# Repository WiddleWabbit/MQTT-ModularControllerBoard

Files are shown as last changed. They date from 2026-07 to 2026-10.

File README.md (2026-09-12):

# MQTT Modular Controller Board

*Currently In Testing - Not Yet Tested*

ESP32-S3-WROOM-1U based motherboard designed to communicate externally via MQTT, and read sensors, control interfaces and other hardware through purpose built modules. For example, actuator control (pumps, solenoids, etc.), and water sensor readings etc.

## Features

- ESP32-S3-WROOM-1U microcontroller with antenna support
- Four module slots using standardized 2x10 pin headers
- Power rails: 12 V, 5 V, and 3.3 V supplied to modules
- High-side reverse polarity protection on 12 V and 5 V inputs
- USB-powered operation for programming and testing (no 12 V required)
- Screw terminal power input
- 4-layer PCB designed for assembly (routing / GND / GND / routing)
- 4 x 3.5mm Mounting Holes

## Architecture

### Core Components
- **Microcontroller**: ESP32-S3-WROOM-1U
- **Power Input**: 12 V via screw terminals
- **Power Conversion**:
  - 12 V → 5 V using TPS563200DDCR (TI WEBENCH design)
  - 5 V → 3.3 V using LDO
- **Maximum Outputs**:
  - 12 V: Limited by external supply
  - 5 V: 3 A total (0.8 A used internally)
  - 3.3 V: 1 A total (0.6 A used by ESP32)

### Module Interface
Each of the four modules connects via two 10-pin headers and receives:
- Power: 12 V (4 pins shared), 5 V (2 pins), 3.3 V (2 pins), GND (4 pins)
- Communication:
  - Shared SPI: CS(per module), MOSI(GPIO11), MISO(GPIO13), SCK(GPIO12)
  - Shared I²C: SDA(GPIO4), SCL(GPIO5)
- Control/Detection:
  - One general-purpose GPIO per module
  - One module detection/sense pin per module
  - Module-specific CS pins.

#### Module Slots (Left to Right)
Slot 1:
- General Purpose: GPIO1
- Module Detection: GPIO2
- CS Pin: GPIO16
  
Slot 2:
- General Purpose: GPIO43
- Module Detection: GPIO44
- CS Pin: GPIO15
  
Slot 3:
- General Purpose: GPIO42
- Module Detection: GPIO41
- CS Pin: GPIO7
  
Slot 4:
- General Purpose: GPIO40
- Module Detection: GPIO39
- CS Pin: GPIO6
  
### Additional Features
- USB micro-B for programming and power (VBUS sense on GPIO08)
- Power indicator LED on 3.3 V rail
- EN button and RESET functionality
- Manual download mode: Hold BOOT button while pressing RESET, then release BOOT

### PCB Stackup
4-layer board:  
Component/Routing → Ground plane → Ground plane → Routing

Impedance Control:
Designed for JLCPCB Impedance Control Stackup of JLC04161H-7628, Finished thickness of 1.59mm.

## Setup and Build

**Firmware**: The PlatformIO firmware includes non-blocking WiFi station
reconnection and a captive-portal setup flow. On first boot, the portal scans
nearby networks and offers a selectable SSID list plus manual SSID entry.

**Programming**:
- Connect via USB micro-B.
- Use ESP32 flashing tools (esptool, Arduino IDE, ESP-IDF, etc.).
- For manual bootloader mode: Hold BOOT button, press RESET, release BOOT.

**Module Development**:
Modules must conform to the 2x10 header pinout with 40mm pitch.
Board uses 2 x 10, 8.5mm Female Headers (A2541HWV-10P). Recommended 3A support.

## Repository Contents

- KiCad schematic and PCB files
- Project configuration
- Backups folder

## License

This documentation is part of MQTT-ModularControllerBoard Project and is licensed under the CERN Open Hardware Licence Version 2 - Permissive (CERN-OHL-P-2.0). 
You may redistribute and modify this documentation under the terms of the CERN-OHL-P-2.0. 
This documentation is distributed WITHOUT ANY EXPRESS OR IMPLIED WARRANTY, INCLUDING OF MERCHANTABILITY, SATISFACTORY QUALITY AND FITNESS FOR A PARTICULAR PURPOSE. See the CERN-OHL-P-2.0 for applicable conditions.

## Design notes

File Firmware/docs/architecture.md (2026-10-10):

# Firmware architecture

[Home](home.md)

## Summary

The controller is seven modules. Each one has a small interface and hides its state machines. `src/main.cpp` is the composition root: it constructs the ESP32 adapters, passes timing constants and `kMqttDeviceId`, and calls `begin` / `update`. It does not sequence the steps inside a module.

Logic depends on hardware ports in `lib/Interfaces/`. ESP32 adapters live in `lib/Drivers/`. Logic does not include Arduino headers.

## Where it sits

Global constructors run before `setup()`. The type modules register their MQTT handlers there, so they exist before `Network::begin()`. `startController()` then calls `moduleBus.begin()`, `network.begin()`, and `serialConsole.begin()`. A latched programming session skips that until the session ends.

`kMqttDeviceId` in `src/main.cpp` is the MQTT topic root used when `mqtt_prefix` is not stored. The layout does not invent that id. `{id}` below means that root. Setting it is described in [configuration.md](configuration.md). Every topic, and a payload to publish when testing, is in the [MQTT reference](reference/mqtt.md).

## What main creates

```text
main.cpp
  Network
    WifiManager
    NtpService
    MqttService
    MqttTopicLayout
    PreferenceNetworkConfigStore
    NetworkRuntime
  ModuleBus
    ModuleHost
      SlotController
    ModuleSlotPublisher
  SensorModule
    SensorPoller
    SensorMqttBridge
  SolenoidModule
    SolenoidPoller
    SolenoidMqttBridge
  PumpModule
    PumpPoller
    PumpMqttBridge
  SerialConsole
    SerialConfigController
    SerialStatusReporter
  Programming
    ProgrammingSession
    IspProgrammer
    UpdiProgrammer
```

The ESP32 adapters (clock, Wi-Fi, NTP, MQTT, preferences, I2C, GPIO, USB serial, SPI, the half-duplex UART, and the programming latch) are also constructed in `main.cpp` and passed in. Sibling modules reach inside `Network` or `ModuleBus` through a private accessor. `main.cpp` does not call those accessors. On the bus, each `SlotController` holds one slot. `ModuleHost` calls I2C. `ModuleSlotPublisher` publishes that slot's public snapshot. The handoff is on the [module bus](module-bus.md) page.

## One pass

`loop()` always calls `network.update()` first. Inbound MQTT commands are queued there. `update()` methods do not wait on the network. Wi-Fi and MQTT retries use wrap-safe elapsed time and exponential backoff. An I2C transaction is bounded by the host's 50 ms timeout.

```mermaid
flowchart TD
  loop["loop()"] --> net["network.update()<br/>Wi-Fi, then NTP, then MQTT"]
  net --> prog{"programming.active()?"}
  prog -->|yes| stk["programming.update()"]
  stk --> still{"still active?"}
  still -->|yes| ret["return"]
  still -->|no| boot["clear the latch<br/>startController() if setup skipped it"]
  prog -->|no| ser["serialConsole.update()"]
  boot --> ser
  ser --> asked{"program command?"}
  asked -->|yes| arm["store the latch, programming.begin(), return"]
  asked -->|no| bus["moduleBus.update()"]
  bus --> sensor["sensorModule.update()"]
  sensor --> solenoid["solenoidModule.update()"]
  solenoid --> pump["pumpModule.update()"]
  pump --> snap["serialConsole.updateStatus()"]
```

An immediate `status` prints inside `serialConsole.update()`, before the modules. The periodic snapshot is `updateStatus()`, after them, so it matches this pass. Heap and PSRAM lines stay in `main.cpp` and print when USB is plugged in.

While a session is active, Wi-Fi, NTP, and MQTT keep running. The console, the bus, and the type modules do not. Desired solenoid and pump commands wait. Their absence windows keep counting, so a session longer than the cutoff turns those outputs off on the next module update.

## Modules

| Module | Interface | What one `update()` does | Page |
| --- | --- | --- | --- |
| `Network` | `begin`, `update`, `publish`, `addMessageHandler`, `apply`, `config` | Wi-Fi, then NTP, then MQTT | [Network](networking.md) |
| `SerialConsole` | `begin`, `update`, `updateStatus` | `update` reads USB lines. `updateStatus` prints the snapshot after the modules | [Serial console](serial-console.md) |
| `ModuleBus` | `begin`, `update`, `quiesce`, `resume` | At most one I2C transaction, then slot status if the text changed | [Module bus](module-bus.md) |
| `SensorModule` | `update` | At most one sensor exchange, then publish what it stored | [Sensor](sensor-module.md) |
| `SolenoidModule` | `update` | At most one solenoid exchange, then publish what it stored | [Solenoid](solenoid-module.md) |
| `PumpModule` | `update` | At most one pump exchange, then publish what it stored | [Pump](pump-module.md) |
| `Programming` | `begin`, `update`, `active` | ISP or UPDI until idle timeout or a confirmed unplug | [Programming](programming.md) |

Poll intervals and command-absence cutoffs are named constants in `src/main.cpp` and are passed into the type modules. Sensor, solenoid, and pump polls are 60 seconds. A solenoid command absent for 15 minutes turns every output off. A pump on/off command absent for 3 minutes turns the pump off. A pump reset does not refresh that window.

`Network` accepts at most four inbound handlers. Sensor, solenoid, and pump register one each, in their constructors. `begin` loads the stored record over the defaults from `main.cpp`, then starts Wi-Fi, MQTT, and NTP. `apply` persists the selected fields and pushes Wi-Fi or MQTT only after that save. An empty broker host stays unconfigured and does not call `connect`.

## Seams

A seam is a contract with two adapters. Hardware ports (`IClock`, `IWifi`, `INtpAdapter`, `IMqttClient`, `IPreferenceStore`, `ISerialPort`, `IBytePort`, `IDigitalPin`, `ISpiMaster`, `IHalfDuplexUart`, `I2cMaster`) have an ESP32 driver and a desktop fake. `INetworkConfigStore` lives in `lib/Logic/Network/` because `PreferenceNetworkConfigStore` and `FakeNetworkConfigStore` are both real adapters. It is not a hardware port. Port behaviour is in [interfaces.md](interfaces.md).

Do not add an interface so one logic class can be replaced by a fake. `WifiManager`, `NtpService`, `MqttService`, `ModuleHost`, and the pollers stay as classes inside their module. Their existing tests stay, because those tests cover edges the module tests do not replace.

## Folders

- `lib/Interfaces/` contains the hardware ports and `ModuleProtocol.h`.
- `lib/Drivers/` contains the ESP32 adapters.
- `lib/Logic/` is one PlatformIO library. Sources live in `Network`, `Console`, `Bus`, `Sensor`, `Solenoid`, `Pump`, and `Programming`.
- `test/test_desktop/fakes/` contains the desktop adapters.
- `test/test_desktop/` contains Unity tests. `test_main.cpp` calls each file's runner. `test_deep_modules.cpp` drives the seven modules. The other files drive the classes inside them.
- `src/main.cpp` composes the product.

`platformio.ini` lists `lib_deps = Logic` on both environments. The library finder does not compile sources that live in subfolders unless the library is named. The `-I lib/Logic/...` flags only expose the headers. Leave `lib_deps` in place.

## Desktop testing

Tests run on the desktop with PlatformIO's `native` environment:

```text
C:\Users\Nathan\.platformio\penv\Scripts\platformio.exe test -e native
```

`test_deep_modules.cpp` drives each module through its public interface: connect and backoff, apply and persistence, empty-broker refusal, slot publish and enumeration, prefix changes, sensor and solenoid and pump commands, absence windows, programming quiesce, and the serial console. The older files keep the inner edges: retry sequences, frame codecs, enumeration faults, poller cycles, and the STK500 and jtag2updi command sets.

The fakes simulate link state, RSSI, time, broker outcomes, subscriptions, publications, inbound messages, persisted settings, USB presence, serial bytes, GPIO levels, SPI, a half-duplex UART, and I2C slaves. The RTC programming record is ESP32-only and is not in these tests. Production builds use `lib/Drivers/`. Test code and fakes are not included.

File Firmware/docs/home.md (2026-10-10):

# Firmware

The controller is seven modules. `src/main.cpp` constructs them and calls
`update()`. It does not run the steps inside a module.

Start here. Three ways to read.

## How the controller runs

Each of these is a short page: what the module creates, and what one `update()` does.

1. [Architecture](architecture.md) — the loop, and who owns whom.
2. [Module bus](module-bus.md) — `SlotController` holds each slot; the host does one I2C transaction; the publisher sends slot status.
3. [Sensor](sensor-module.md), [Solenoid](solenoid-module.md), and [Pump](pump-module.md) — one daughter type each.
4. [Network](networking.md) — Wi-Fi, then NTP, then MQTT.
5. [Serial console](serial-console.md) — USB lines, then the snapshot.
6. [Configuration](configuration.md) — `set` stages, `apply` stores, and the three names.
7. [Programming](programming.md) — ISP or UPDI on one slot.
8. [Hardware ports](interfaces.md) — the interfaces Logic calls.

## When you need a byte, a state, or a test

The [reference index](reference/index.md) is the technical wiki. Each module page there has the commands, the sequences, the errors, and the desktop test that covers them. The [MQTT reference](reference/mqtt.md) lists every subscription and publication, with the payload to publish when testing.

## Building a daughter module

A daughter module is the board in a slot. That is separate from the classes inside a controller module.

1. [What a daughter module must do](daughter/contract.md).
2. [Frames, with worked bytes](daughter/frames.md).
3. [Add a new type](daughter/new-type.md) — the board, and the controller module that talks to it.

`lib/Interfaces/ModuleProtocol.h` is the command list daughter projects copy. If a byte on these pages and the header disagree, the header is the one the controller compiles.

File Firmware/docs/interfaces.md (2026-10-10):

# Hardware interfaces

[Home](home.md)

Hardware ports live in `lib/Interfaces/`. Drivers implement them for
ESP32/Arduino. Desktop tests use controllable fakes. A port is a seam
because both adapters exist. Logic-to-logic interfaces are not added here.

## `IClock`

- `millis()` returns a monotonic millisecond counter.
- Values may wrap at the counter width; consumers must use unsigned elapsed-time
  arithmetic.
- The fake clock supports deterministic advancement and wraparound tests.

## `IWifi`

- `begin(ssid, password)` starts one nonblocking station attempt.
- `status()` reports `Disconnected`, `Connecting`, or `Connected`.
- `rssi()` reports station signal strength in dBm.
- `localIp()` reports the station IPv4 address, or `0.0.0.0` when none is
  assigned.
- `setHostname(hostname)` stores the DHCP hostname committed on the next
  station start.
- `resetStationMode()` stops station mode so the next start commits that name.
  The ESP32 driver uses this because Arduino-ESP32 2.0 applies the hostname
  only when station mode changes.
- `disconnect()` stops the current attempt or connection.
- The driver must not wait for association inside `begin()`.
- The fake records credentials, hostname commits, mode resets, and
  disconnects, can return a sequence of link states, and exposes a settable
  RSSI and address.

## `INtpAdapter`

- `configure(server1, server2, server3, utcOffset, daylightOffset)` starts or
  refreshes platform SNTP configuration.
- `isSynchronized()` reports whether a valid epoch is available.
- `currentTime()` returns the synchronized Unix epoch, or the platform value
  when synchronization is not yet available.
- Configuration is asynchronous; the adapter must not block waiting for NTP.
- The fake records all configuration values and exposes synchronization and
  epoch controls.

## `IMqttClient`

- `setCallback()` installs the inbound payload callback and opaque context.
- `connect()` performs one broker attempt and returns its result.
- `connected()` reports the current broker state.
- `disconnect()` closes the broker session.
- `subscribe()` returns whether a topic subscription was accepted.
- `publish()` returns whether a publication was accepted. It takes a retain flag and no QoS. Outbound messages are QoS 0.
- `loop()` services the underlying MQTT transport.
- The topics this firmware subscribes to and publishes are in the [MQTT reference](reference/mqtt.md).
- The fake records all calls, supports result sequences, and can inject
  inbound messages.

The production adapters are intentionally thin: `Esp32Wifi` uses `WiFi`,
`Esp32NtpAdapter` uses `configTime()` and the system epoch, `Esp32Clock` uses
Arduino `millis()`, and `PubSubClientAdapter` wraps an existing
`PubSubClient`.

## `INetworkConfigStore`

This contract is not a hardware port and does not live in `lib/Interfaces/`.
It is inside `Network`. The load and save rules are in the
[network reference](reference/networking.md).

## `IPreferenceStore`

- `open` / `close` bracket one read or write session.
- `contains` reports a key without reading it. Callers use it before
  `readString` so a missing key does not surface a storage error.
- `writeString` returns the number of characters stored. Empty text returns 0
  on both success and failure; `contains` distinguishes them.
- `writeUShort` returns 2 on success.

## `ISerialPort`

- `isPlugged()` is a nonblocking snapshot of the USB serial plug state.
- `available()` reports pending bytes, `read()` consumes one byte, and
  `writeLine()` emits one response line.
- The serial controller must not consume or emit bytes while the USB serial
  link is unplugged.
- Fakes must provide queued input and inspectable output.

## `IBytePort`

- Raw bytes for programming traffic. Line framing stays on `ISerialPort`.
- `isPlugged()`, `available()`, and `read()` match the serial port.
- `write(data, length)` sends a buffer. A null pointer or a zero length
  writes nothing.
- The ESP32 adapter is the same USB CDC object as `ISerialPort`.
- Fakes queue input and record every written byte.

## `ISpiMaster`

- `begin(clockHz)` starts mode 0, MSB first, with SCK idle low.
- `end()` releases the bus.
- `transfer()` clocks one byte and returns the byte shifted in.
- The programmer calls `begin()` before it drives reset low, and it keeps
  the clock at 125 kHz.
- Fakes record the clock, the order `begin()` was called, and every byte,
  and they return a scripted MISO stream.

## `IHalfDuplexUart`

- `attach(gpio, baud)` claims one GPIO as both TX and RX.
- `detach()` stops the UART and releases the pin.
- `available()` reports pending bytes. `read()` returns one byte, or -1
  when none arrives.
- `write()` sends raw bytes. The caller reads the local TX echo before
  the next byte. The ESP32 adapter is UART1, 8E2, and does not discard
  that echo. UART0 stays free because GPIO43 and GPIO44 are module pins.
- Fakes queue the echo ahead of any scripted target byte, and they record
  the GPIO, the baud, and every transmitted byte.

## `IDigitalPin`

- `setMode()` selects `DigitalInput`, `DigitalInputPullup`, `DigitalOutput`,
  or `DigitalOutputOpenDrain`. Names avoid Arduino `INPUT`/`OUTPUT` macros.
- `DigitalOutputOpenDrain` drives LOW as the safe default after mode change.
- `read()` is true when the pin is HIGH. Sense present is LOW.
- `write()` drives an output; true is HIGH / open-drain Hi-Z.
- The ESP32 driver must use Arduino `pinMode` so UART0 detaches from GPIO43/44.
- Fakes must record mode, writes, push-pull HIGH attempts, and an external
  level override for sense.

## `I2cMaster`

- `begin()`, `setClockHz()`, and `setTimeoutMs()` configure the bus.
- `write()` issues STOP. `writeRead()` uses a repeated start. A NACK,
  timeout, or bus error is returned to the caller. The ESP32 driver does
  not print a NACK. The console reports `Slot N: Nack` once.
- `recover()` clocks SCL up to nine times, issues STOP, and re-inits. It is
  best-effort; a still-stuck SDA needs the module unplugged.
- Results are `Ok`, `Nack`, `Timeout`, or `BusError`.
- Fakes record operations (address, tx, rxLen, STOP) and dispatch to
  simulated modules. They must support stuck-SDA and two-ACK collision.

Module command IDs, frame layout, and CRC-8/SMBus live in copyable
`lib/Interfaces/ModuleProtocol.h`. Behaviour a daughter board must follow
is in [the daughter contract](daughter/contract.md).

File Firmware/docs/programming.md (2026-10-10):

# Programming

[Home](home.md) · Reference: [Programming](reference/programming.md)

## Summary

`Programming` is an ISP or UPDI session on one firmware slot, 1 through 4. `program 1 isp` uses the shared SPI pins and that slot's CS pin as RESET. `program 3 updi` uses only that slot's CS pin as the UPDI wire. A line without both a slot and a method replies `ERR program` and does not start a session.

## Where it sits

`main.cpp` constructs it with the USB byte port, the SPI master, the half-duplex UART, the four CS pins, `kProgrammingPins`, `ModuleBus`, the clock, `kProgrammingIdleTimeoutMs` (60 seconds), and `kProgrammingUnplugTimeoutMs` (1 second). `loop()` calls `network.update()` first. While `active()` is true it calls `programming.update()` and returns, unless the session ended on that pass.

`serialConsole.update()` recognizes the program line and returns before the bus. `loop()` then stores the RTC latch and calls `begin(slot, method)`.

## What it creates

```text
main.cpp
  Programming
    ProgrammingSession     silence timer and the seen-then-absent unplug rule
    IspProgrammer          STK500v1 subset avrdude uses, 125 kHz SPI
    UpdiProgrammer         jtag2updi, one open-drain GPIO, 115200 8E2
```

`begin(slot, method)` quiesces the bus. A slot outside 1..4 returns without quiescing. A second `begin` while the session is active does not rebind the pin or the UART. While the session is active the console, the bus, and the type modules do not run. Wi-Fi, NTP, and MQTT do. Desired solenoid and pump commands wait, and their absence windows keep counting.

## One update

```mermaid
flowchart TD
  cmd["program N isp or program N updi"] --> ok["OK programming, pin line, RTC record"]
  ok --> begin["Programming.begin(slot, method) quiesces the bus"]
  begin --> step["programming.update(): one ISP or UPDI step"]
  step --> done{"60 s of silence, or 1 s absent after the link was seen?"}
  done -->|no| step
  done -->|yes| resume["Release the claimed CS pin, clear the record, resume the bus"]
```

A USB-open restart keeps the record, so `setup()` enters the same slot and method without the banner and without `startController()`. The reset button and a power cycle clear it. An older single-word ISP marker does not resume. Pins, the two host tools, and the wire sequences are in the reference.

## What is stored, and who reads it

The latch is one record in RTC slow memory (`.rtc_noinit`): magic, slot, and method. `setup()` reads it. `loop()` clears it when the session ends. Ending the session does not reset the chip. If init already ran, the power-on lines are not printed again.

## See also

- [Programming reference](reference/programming.md) — jumper pins, STK500, jtag2updi, the unplug rule, tests.
- [Configuration reference](reference/configuration.md) — the accepted `program` lines and `ERR program`.
- [MQTT reference](reference/mqtt.md) — commands that can still arrive while a session is active.
- [Serial console](serial-console.md)
- [Module bus](module-bus.md)
- [Architecture](architecture.md)

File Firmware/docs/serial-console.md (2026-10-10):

# Serial console

[Home](home.md) · Reference: [Serial console](reference/serial-console.md)

## Summary

`SerialConsole` reads USB command lines and prints the status snapshot. `update()` reads lines. `updateStatus()` prints the snapshot after the modules, so the slot lines match this pass. An immediate `status` command prints inside `update()`, before the modules.

USB plug state gates input and both kinds of print. Heap and PSRAM lines stay in `main.cpp`. They are not part of this snapshot.

## Where it sits

`main.cpp` constructs it with the serial port, the clock, `Network`, `ModuleBus`, `kSerialStatusIntervalMs` (10 seconds), and `kProgrammingPins`. `startController()` calls `serialConsole.begin()` after `network.begin()`. `loop()` calls `update()` before the bus, and `updateStatus()` after the pump module.

## What it creates

```text
main.cpp
  SerialConsole
    SerialConfigController     set, apply, status, program
    SerialStatusReporter       Wi-Fi, NTP, MQTT, and four slot lines
```

The reporter is constructed with the Wi-Fi, NTP, and MQTT services from `Network`, and with `ModuleHost` from `ModuleBus`. `main.cpp` does not construct it. It reads snapshots only. It does not call `ping()` or `echo()`.

## One pass

```mermaid
flowchart TD
  upd["SerialConsole.update()"] --> plug{"USB plugged in?"}
  plug -->|no| stop["Read nothing"]
  plug -->|yes| line["Read a complete line"]
  line --> cmd{"Command"}
  cmd -->|set| stage["Stage one field"]
  cmd -->|apply| save["NetworkRuntime saves the staged fields"]
  cmd -->|status| now["Print one snapshot now"]
  cmd -->|program| arm["Ask loop to start the programming session"]
```

`updateStatus()` prints the same snapshot when periodic reporting is on, the link is plugged in, and `kSerialStatusIntervalMs` has elapsed. `status` prints even when periodic reporting is off. It does not change the on/off flag. A successful immediate print restarts the wait until the next periodic snapshot.

A slot that reaches `Fault Nack` also prints one line, `Slot N: Nack`, on the next `updateStatus()`. That line is not repeated while the slot keeps failing and retrying. It is printed again after the slot is empty, online, or unsupported and then faults again. The I2C driver does not print its own NACK line.

`program` inside `update()` makes `loop()` store the RTC latch and call `programming.begin()` before the bus runs. The command list is in [Configuration](configuration.md). The session is in [Programming](programming.md).

## What is stored, and who reads it

Staged fields live in `NetworkRuntime` until `apply`. The on/off flag is the NVS key `status_report`. The snapshot interval is session RAM from `main.cpp`. No command stores it. Reboot restores 10 seconds.

The four slot lines come from `ModuleHost` public snapshots. Wi-Fi, NTP, and MQTT lines come from those services.

## See also

- [Serial console reference](reference/serial-console.md) — the seven lines, plug gating, tests.
- [Configuration](configuration.md)
- [Programming](programming.md)
- [Architecture](architecture.md)

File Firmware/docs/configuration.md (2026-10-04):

# Runtime configuration

[Home](home.md) · Reference: [Commands and stored fields](reference/configuration.md)

## Summary

`set` stages one field. `apply` stores only the fields staged since the last successful apply, then restarts Wi-Fi when a Wi-Fi field changed and MQTT when an MQTT field changed. A failed save leaves the active record unchanged and leaves the staged fields in place for a retry. An empty `apply` replies `OK applied` and does not reconnect.

## Where it sits

`SerialConfigController`, inside [Serial console](serial-console.md), parses complete lines while USB is plugged in. `NetworkRuntime`, inside [Network](networking.md), owns the active strings and the staged copy. `PreferenceNetworkConfigStore` writes them through `IPreferenceStore`.

## One apply

```mermaid
flowchart TD
  setc["set key value"] --> staged["Staging copy only"]
  staged --> apply["apply"]
  apply --> any{"Any field staged?"}
  any -->|no| ok["OK applied, no reconnect"]
  any -->|yes| save["Save those fields"]
  save --> fail{"Save succeeded?"}
  fail -->|no| keep["Active record unchanged, staged fields kept"]
  fail -->|yes| wifi{"A Wi-Fi field changed?"}
  wifi -->|yes| wre["Restart Wi-Fi"]
  save --> mqtt{"An MQTT field changed?"}
  mqtt -->|yes| mre["Restart MQTT"]
```

Setting a credential or a broker field to an empty string stores that empty string. An empty MQTT host stays `Unconfigured` and does not call `connect`.

## The three names

| Setting | Command | Missing key |
| --- | --- | --- |
| DHCP hostname | `set wifi.hostname` | `watering-controller` from `setup()`, not written until applied |
| MQTT client id | `set mqtt.client` | `watering-controller`, then saved on boot |
| Topic prefix `{id}` | `set mqtt.prefix` | `kMqttDeviceId` in `src/main.cpp` (`watering`), not written until applied |

The layout does not invent `watering`. The hostname, the client id, and the prefix are independent. A DHCP rename does not move topics. Two boards on one broker need different client ids and different prefixes. Commissioning sets all three to the same name. The character rules, the replies, and that example are in the [configuration reference](reference/configuration.md).

`{id}` in the other pages is this prefix.

## See also

- [Configuration reference](reference/configuration.md) — every key, NVS names, prefix generation.
- [MQTT reference](reference/mqtt.md) — every topic under that prefix, and a payload to publish when testing.
- [Serial console](serial-console.md)
- [Network](networking.md)

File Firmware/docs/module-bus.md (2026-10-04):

# Module bus

[Home](home.md)

Reference: [pins, phases, the lock, and publication](reference/module-bus.md).

## Summary

`ModuleBus` is the four-slot I2C bus. `main.cpp` creates it. A `SlotController` holds each slot's state. `ModuleHost` owns those four controllers, grants the enumeration lock, and is the class that talks to the I2C master. `ModuleSlotPublisher` reads the public snapshot and publishes a retained slot line when that line's text changed. Each `update()` lets the host do at most one I2C transaction, then asks the publisher. Sensor, solenoid, and pump borrow the same host later in the pass, each for one transaction of their own.

## Where it sits

`main.cpp` constructs `ModuleBus` with the I2C master, the clock, the four sense / MOD / CS pin sets, and `Network`. `loop()` calls `moduleBus.update()` after the console has read a command, and before the type modules. See [Architecture](architecture.md).

`Programming::begin()` calls `quiesce()` so the bus stays quiet during an ISP session, and `resume()` when the session ends. `loop()` skips `moduleBus.update()` for the whole session, so the publisher is quiet then too.

## What it creates

```text
main.cpp
  ModuleBus                 calls the host, then the publisher
    ModuleHost              owns the four controllers, the lock, and the I2C calls
      SlotController        one per slot; holds that slot's state and proposes the next step
    ModuleSlotPublisher     turns the public snapshot into retained {id}/slot/1 .. {id}/slot/4
```

`SlotController` watches SENSE, MOD, and CS for its slot. It remembers the phase, the address, the identity, and the last fault, and it proposes the next I2C operation. `ModuleHost` performs that operation and writes the result back onto the same controller. `ModuleSlotPublisher` reads the public snapshot through the host. I2C stays in the host. MQTT stays in the publisher.

## How they link

```text
each SlotController advances its pins
        |
ModuleHost grants the lock to the lowest slot that wants it
        |
the lock owner's enumeration step, else one due health ping, else no I2C
        |
applyI2cResult() on that slot when a transaction ran
        |
ModuleSlotPublisher reads every slot's public snapshot
        |
retained {id}/slot/N for each body the broker has not accepted yet
```

The lock owner's enumeration step is the transaction when one is due. A slot can hold the lock while it waits out the MOD settle or a retry gap. On those passes it proposes nothing, and a health ping for another slot can use the transaction. With neither due, the pass has no I2C. The publisher still runs, and it skips any slot whose text the broker already accepted.

## One update

```mermaid
flowchart TD
  upd["ModuleBus.update()"] --> pins["Each SlotController reads SENSE and advances its phase"]
  pins --> lock["ModuleHost grants the lock to the lowest waiting slot"]
  lock --> pick{"Lock owner has an enumeration step due?"}
  pick -->|yes| issue["Host issues that one transaction<br/>and the slot stores the result"]
  pick -->|no| health{"A health ping is due?"}
  health -->|yes| ping["Host issues that one ping<br/>and the slot stores the result"]
  health -->|no| pub["ModuleSlotPublisher"]
  issue --> pub
  ping --> pub
  pub --> changed{"Text differs from the last payload the broker accepted?"}
  changed -->|yes| mqtt["Publish retained {id}/slot/N"]
  changed -->|no| done["Leave that topic as it is"]
```

Sibling modules reach the host through `ModuleBus::host()`. `main.cpp` does not call that. A type module's `exchange()` is a later call in the same `loop()` pass. It uses the address and type the slot controller stored.

## What is stored, and who reads it

Each `SlotController` stores that slot:

- the private phase, which `state()` folds into `Empty`, `Debouncing`, `Enumerating`, `Online`, `Unsupported`, or `Fault`
- the assigned address, which stays 0 until a ping at that address succeeds. The ping follows `SET_ADDRESS`, or it follows three NACKs at `0x0A`. The slot address is `0x10` plus the slot index. Unplug and a controller reset both clear it.
- type id, protocol version, firmware version, and identity epoch
- the last fault (`None`, `Nack`, `BadCrc`, `BadFrame`, `Timeout`, or `Busy`)

`identityEpoch` increases by one each time `GET_IDENTITY` succeeds, including after the module restarts. Sensor, solenoid, and pump read it through the host. They clear that slot's cached readings when the slot leaves their type, and when this count changes.

`ModuleHost` stores which slot holds the enumeration lock (`-1` when the lock is free) and which slot to ask next for a health ping. Its readers (`state`, `address`, `typeId`, `protocolVersion`, `firmwareVersion`, `identityEpoch`, `fault`, `typeName`) forward to the matching controller. An out-of-range index reads as empty.

`ModuleSlotPublisher` stores, per slot, the last payload the broker accepted and whether that publish succeeded, plus the topic generation those payloads belong to. Every update builds the text again from the host. The words come from `writeSlotStatusBody` in `SlotStatusText`: `Empty`, `Debouncing`, `Enumerating`, `Online Sensor addr=0x10`, `Unsupported type=0x02AA addr=0x12`, `Fault Nack`. Firmware index 0 is topic `{id}/slot/1`.

- `SerialConsole` prints that same body with a `Slot N:` prefix.
- `SensorModule`, `SolenoidModule`, and `PumpModule` call `exchange()` for their own command after this `update()` has returned, and they keep their own samples.
- `Programming` calls `quiesce()` and `resume()`. While the host is quiesced, an `update()` leaves every slot where it is.

## See also

- [Module bus reference](reference/module-bus.md) — the phase map, the publisher's retry rule, pins, the lock, faults, and health pings.
- [MQTT reference](reference/mqtt.md) — the slot topics, and the payload text.
- [What a daughter module must do](daughter/contract.md)
- [Architecture](architecture.md)

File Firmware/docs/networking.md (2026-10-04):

# Network

[Home](home.md) · Reference: [Network](reference/networking.md)

## Summary

`Network` is Wi-Fi, NTP, MQTT, and the stored settings. `update()` runs those three in that order and does not decode sensor, solenoid, or pump commands. Inbound payloads are delivered to the handlers those modules registered.

An empty broker host stays unconfigured and does not call `connect`.

## Where it sits

`main.cpp` constructs it with the Wi-Fi, NTP, and MQTT adapters, the clock, the preference store, `kMqttDeviceId`, `kNtpConfig`, and `kNetworkTiming`. `startController()` calls `network.begin()` after `moduleBus.begin()`. `loop()` calls `network.update()` first on every pass, including while an ISP session is active.

The type modules exist before `begin()`, because their constructors register handlers.

## What it creates

```text
main.cpp
  Network
    WifiManager                      Idle, Connecting, Connected, Backoff
    NtpService                       Idle, WaitingForSync, Synchronized
    MqttService                      connect, subscribe, publish
    MqttTopicLayout                  topic strings and the generation counter
    PreferenceNetworkConfigStore     NVS through IPreferenceStore
    NetworkRuntime                   active record, staged edits, apply
```

`main.cpp` does not call those classes. Sibling modules reach MQTT and the topic tree through private accessors.

## One update

```mermaid
flowchart TD
  upd["Network.update()"] --> wifi["WifiManager.update()"]
  wifi --> ntp["NtpService.update()"]
  ntp --> mqtt["MqttService.update(wifi ready)"]
  mqtt --> fan["Deliver queued payloads to the registered handlers"]
```

None of these steps waits for a connection. Retries use wrap-safe elapsed time and capped exponential backoff.

`begin()` loads the stored record over the defaults from `main.cpp`, then starts Wi-Fi, MQTT, and NTP. `apply` stores the staged fields and pushes Wi-Fi or MQTT only after that save.

## What is stored, and who reads it

`NetworkRuntime` holds the active strings. Staged serial edits cannot change them before `apply`. `MqttTopicLayout` holds the topic tree for `{id}`. Its generation starts at 1 and increases when the id text changes, so publishers send their current values once under the new root.

`{id}` is `kMqttDeviceId` (`watering`) until `mqtt_prefix` is stored. The layout does not invent that id. Setting it is described in [Configuration](configuration.md).

The hostname, the MQTT client id, and the topic prefix are three different settings.

## See also

- [Network reference](reference/networking.md) — states, subscriptions, the generation counter, the config store.
- [MQTT reference](reference/mqtt.md) — every command, result, and a payload to publish when testing.
- [Configuration](configuration.md)
- [Architecture](architecture.md)

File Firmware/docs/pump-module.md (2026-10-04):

# Pump module

[Home](home.md) · Reference: [Pump](reference/pump-module.md)

## Summary

`PumpModule` talks to daughter boards of type `0x0300`. A board drives one pump. The module reads it when the board is identified, reads it again on the poll interval, and publishes `on`, `off`, or `fault`. `{id}/pump` names the desired on or off state, or asks for a reset. `SET_PUMP` is sent only when the known state differs, and it is not sent while the pump is faulted.

If no accepted on/off command arrives for `kPumpCommandTimeoutMs` (3 minutes), a pump that is on is turned off. A reset does not refresh that window, and it does not clear a fault by itself. `RESET_PUMP` is sent only after `{id}/pump` says `reset`.

## Where it sits

`main.cpp` constructs it with `ModuleBus`, `Network`, the clock, `kPumpPollIntervalMs` (60 seconds), and the absence window. The constructor registers the `{id}/pump` handler. `loop()` calls `pumpModule.update()` after the solenoid module.

## What it creates

```text
main.cpp
  PumpModule
    PumpPoller         one query per pass; per-slot state and timer
    PumpMqttBridge     records on, off, or reset; publishes the stored state
```

The callback only records the request. `ModuleHost` is the only I2C caller. This exchange is separate from the host transaction and from the sensor and solenoid queries.

## One update

```mermaid
flowchart TD
  upd["PumpModule.update()"] --> poll["PumpPoller: at most one exchange"]
  poll --> order["A missing state, else RESET, else SET, else the periodic read"]
  order --> mem["Store the state"]
  mem --> bridge["PumpMqttBridge"]
  bridge --> pub{"A state was stored this pass?"}
  pub -->|yes| mqtt["Publish retained on, off, or fault"]
  pub -->|no| quiet["Leave the broker as it is"]
```

A reset waits until the state is known. When it returns off or on and the desired state still differs, a later pass sends `SET_PUMP`. A reset that still returns fault is published and not followed by `SET_PUMP`.

## What is stored, and who reads it

Each slot keeps its own state, desired on/off, and poll timer. The absence window is one timer for every pump: any accepted on/off command restarts it. Faulted pumps are not reset when the window elapses. The bridge publishes `{id}/slot/N/pump`. Unplug publishes retained `unavailable` once.

Serial status prints the slot line only. The pump state is the MQTT payload.

## See also

- [Pump reference](reference/pump-module.md) — commands, reset, the cutoff, tests.
- [MQTT reference](reference/mqtt.md) — the pump topics, and a payload to publish when testing.
- [Daughter contract](daughter/contract.md)
- [Module bus](module-bus.md)
- [Architecture](architecture.md)

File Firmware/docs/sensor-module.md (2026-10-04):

# Sensor module

[Home](home.md) · Reference: [Sensor](reference/sensor-module.md)

## Summary

`SensorModule` talks to daughter boards of type `0x0200`. A board reports up to 16 inputs. The module learns that count when the board is identified, then reads presence and a raw value for each input. Every stored reading is published, including a repeated value.

Wire indexes are 0-based. MQTT slot and sensor numbers are 1-based. The controller does not scale the value.

## Where it sits

`main.cpp` constructs it with `ModuleBus`, `Network`, the clock, and `kSensorPollIntervalMs` (60 seconds). The constructor registers the handler for `{id}/sensor/read` and `{id}/sensor/connected`, before `Network::begin()`. `loop()` calls `sensorModule.update()` after `moduleBus.update()` and before the solenoid module.

## What it creates

```text
main.cpp
  SensorModule
    SensorPoller         one query per pass; per-slot count, samples, and timer
    SensorMqttBridge     publishes stored readings and the connected list
```

`ModuleHost`, inside the bus, is the only I2C caller. The poller's exchange is separate from the one transaction inside `moduleBus.update()`.

## One update

```mermaid
flowchart TD
  upd["SensorModule.update()"] --> poll["SensorPoller: at most one exchange"]
  poll --> order["Immediate read, else a missing count, else the next cycle step"]
  order --> mem["Store the count or the sample"]
  mem --> bridge["SensorMqttBridge"]
  bridge --> pub{"A reading was stored, or the connected list changed?"}
  pub -->|yes| mqtt["Publish the retained reading, and the list when it changed"]
  pub -->|no| quiet["Leave the broker as it is"]
```

The callback for `{id}/sensor/read` only enqueues a slot and a sensor index. The poller sends `GET_SENSOR_READING` on a later pass. While the count is still unknown, that request waits and the count query runs instead. `{id}/sensor/connected` only asks for the connected-input list. It does not enqueue a reading.

## What is stored, and who reads it

Each slot keeps its own count, samples, revision, and poll timer. The bridge reads those and publishes `{id}/slot/N/sensor/M` when a reading was stored, and `{id}/slot/N/sensors` as the count plus the connected indexes. Unplug publishes retained `unavailable` once for that slot's inputs and for its list. Another slot keeps its own cache.

Serial status prints the slot line (`Online Sensor addr=0x10`). It does not print individual inputs.

## See also

- [Sensor reference](reference/sensor-module.md) — commands, poll order, publish rules, tests.
- [MQTT reference](reference/mqtt.md) — the sensor topics, and a payload to publish when testing.
- [Daughter contract](daughter/contract.md)
- [Module bus](module-bus.md)
- [Architecture](architecture.md)

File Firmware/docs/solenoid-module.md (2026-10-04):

# Solenoid module

[Home](home.md) · Reference: [Solenoid](reference/solenoid-module.md)

## Summary

`SolenoidModule` talks to daughter boards of type `0x0100`. A board drives up to 16 outputs. The module learns that count when the board is identified, reads each output, and publishes `on`, `off`, or `disconnected`. An MQTT command names the desired on/off state of every output. The module sends `SET_SOLENOID` only where the known state differs.

If no accepted command arrives for `kSolenoidCommandTimeoutMs` (15 minutes), every output is turned off. Commands are expected about once a minute, and each one names the full set.

## Where it sits

`main.cpp` constructs it with `ModuleBus`, `Network`, the clock, `kSolenoidPollIntervalMs` (60 seconds), and the absence window. The constructor registers the handler for `{id}/solenoids` and `{id}/solenoids/connected`. `loop()` calls `solenoidModule.update()` after the sensor module.

## What it creates

```text
main.cpp
  SolenoidModule
    SolenoidPoller         one query per pass; per-slot count, states, and timer
    SolenoidMqttBridge     records desired state; publishes stored states
```

The callback only records the desired state. It does not touch I2C. `ModuleHost` is the only I2C caller. This exchange is separate from the host transaction and from the sensor query, so one `loop()` can carry one of each.

## One update

```mermaid
flowchart TD
  upd["SolenoidModule.update()"] --> poll["SolenoidPoller: at most one exchange"]
  poll --> order["A missing count, else a command step, else the next state read"]
  order --> mem["Store the count or the state"]
  mem --> bridge["SolenoidMqttBridge"]
  bridge --> pub{"A state was stored, or the inventory changed?"}
  pub -->|yes| mqtt["Publish the retained output, and the connected list when it changed"]
  pub -->|no| quiet["Leave the broker as it is"]
```

A command step reads an output whose state is still unknown, or sends `SET_SOLENOID` where the known state differs. A disconnected output is left alone. A command whose word count does not match the module count is not applied.

## What is stored, and who reads it

Each slot keeps its own count, output states, desired state, and poll timer. The absence window is one timer for the whole controller: any accepted `{id}/solenoids` command restarts it. The bridge publishes `{id}/slot/N/solenoid/M` from the stored state, and `{id}/slot/N/solenoids` as the count plus the connected indexes.

Serial status prints the slot line only.

## See also

- [Solenoid reference](reference/solenoid-module.md) — commands, the cutoff, the inventory, tests.
- [MQTT reference](reference/mqtt.md) — the solenoid topics, and a payload to publish when testing.
- [Daughter contract](daughter/contract.md)
- [Module bus](module-bus.md)
- [Architecture](architecture.md)

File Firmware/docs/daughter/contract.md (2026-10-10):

# What a daughter module must do

[Home](../home.md)

The controller is the only I2C master. Four slots share SDA and SCL. Your board sits in one slot and answers the frames below. Copy `lib/Interfaces/ModuleProtocol.h` for the command bytes and `crc8Smbus()`.

If this page and the header disagree on a byte value, the header is the one the controller compiles.

Worked bytes are in [Frames](frames.md). Choosing a type id, and the controller-side module that talks to a new board, are in [Add a new type](new-type.md). How the host walks the slots is in the [module bus reference](../reference/module-bus.md).

## You must

- Tie SENSE to GND while the board is seated. The controller's pull-up reads LOW as present.
- Leave the I2C slave off until MOD is released. The controller uses MOD as an input with a pull-up when it is not selecting you.
- ACK `0x0A` only while MOD is low, within 5 ms of that edge (`kModGateMaxMs`). Never ACK `0x0A` as a reset default.
- NACK general call `0x00`. Do not become a master.
- On `SET_ADDRESS`, take the new address after STOP, then ACK it with MOD in either state. The controller will not hold MOD low after that.
- Answer `PING` and `GET_IDENTITY`. `GET_IDENTITY` returns type id (`u16`), protocol version (`u8`), and firmware version (`u16`), big-endian. Protocol version is 1.
- Use a type id from [Add a new type](new-type.md).
- Reply to a repeated-start read with the real frame, then `0xFF` until 19 bytes have been clocked. ACK the extra clocks.
- Compute CRC-8/SMBus over every frame byte except the CRC byte. Polynomial `0x07`, init `0x00`, no reflection, xor-out `0x00`. The check value for the ASCII bytes `123456789` is `0xF4`.

## You must not

- Drive SDA or SCL except as an open-drain slave.
- Treat MOD as part of normal operation after your address is assigned.
- Answer another type's commands. An unknown command returns status `UnknownCmd`.

## Frame

```text
byte 0     length    = 2 + payload length
byte 1     command on the way in, status on the way out
bytes 2..  payload   0 to 16 bytes, big-endian
last byte  crc8      over bytes 0 .. length-1
```

The host always `writeRead`s 19 bytes. It checks the CRC at `rx[length]` and ignores the pad.

Status bytes:

| Value | Name | Meaning |
| ---: | --- | --- |
| `0x00` | Ok | Payload follows |
| `0x01` | BadCrc | Request CRC did not match |
| `0x02` | UnknownCmd | This type does not implement that command |
| `0x03` | BadLength | Index or payload length is wrong |
| `0x04` | Busy | Same command will be sent again |
| `0x05` | Unsupported | Command is known and refused |

## Shared commands

| Cmd | Name | What the host sends |
| --- | --- | --- |
| `0x01` | PING | `writeRead` 19, empty payload |
| `0x02` | GET_IDENTITY | `writeRead` 19, empty payload. Ok payload is 5 bytes |
| `0x03` | SET_ADDRESS | 4-byte write plus STOP. No read |
| `0x40` | ECHO | IdentityEcho `0x0001` only. Other types return `UnknownCmd` |

Identity payload, big-endian:

```text
type id hi, type id lo, protocol version, firmware hi, firmware lo
```

An Ok identity frame has length byte `0x07` (2 + 5). Any other Ok length is a bad frame.

`SET_ADDRESS` is a 4-byte write and a STOP, not a read:

```text
03 03 <addr> <crc>
```

`<addr>` is `0x10` plus the slot index. Slot 1 is `0x10`, slot 4 is `0x13`. Commit that address after STOP, even if MOD then goes high. Assigned addresses the host will use are `0x10` through `0x13`. The header allows `0x10` through `0x6F`.

## Timing the host will use

The bus clock is 100 kHz. Stretch the clock no longer than 40 ms (`kClockStretchMaxMs`).

After SENSE has been low through the 50 ms debounce, the host waits 200 ms (`bootWaitMs`) before the first transaction. It then holds MOD low for 10 ms (`modSettleMs`) and pings `0x0A`. Be answering by the end of that boot wait. The full host table is in the [module bus reference](../reference/module-bus.md).

## After you are online

The controller health-pings about once a second. Your type page says which further commands arrive, and in what order:

- Sensor `0x0200` — [Sensor reference](../reference/sensor-module.md)
- Solenoid `0x0100` — [Solenoid reference](../reference/solenoid-module.md)
- Pump `0x0300` — [Pump reference](../reference/pump-module.md)

Wire indexes on those pages are 0-based. MQTT slot and channel numbers are 1-based.

The module protocol does not use SPI. During programming the selected slot's CS pin can be taken as AVR RESET or as the UPDI wire. See [programming.md](../programming.md). Motherboard GPIO numbers for SENSE, MOD, and CS are in the [module bus reference](../reference/module-bus.md).

## Checklist

- SENSE to GND when seated
- I2C slave disabled until MOD is an input with a pull-up
- Never ACK `0x0A` as a reset default
- ACK `0x0A` only while MOD is low, within 5 ms
- 7-bit addresses, NACK `0x00`, not an I2C master
- `SET_ADDRESS` is a 4-byte write plus STOP, committed after STOP
- Repeated-start `writeRead` for `PING` and `GET_IDENTITY`
- Response padded to 19 bytes with `0xFF`
- `protocolVersion == 1`
- Type id from [Add a new type](new-type.md), and only that type's commands

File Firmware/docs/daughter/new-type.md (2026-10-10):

# Add a new type

[Home](../home.md) · [What a daughter module must do](contract.md)

A new daughter board needs two things: firmware on the board that answers the contract, and a controller module that polls it and publishes it. Sensor (`lib/Logic/Sensor/`) is the pattern to copy. Solenoid and pump are the same shape.

## Type id

Pick an unused id. The range reserves later boards of one kind.

| Range | Use |
| --- | --- |
| `0x0001` | IdentityEcho. Health ping only. `loop()` does not poll `ECHO`. |
| `0x0100` | Solenoid module. Taken. |
| `0x0101–0x01FF` | Further actuator types |
| `0x0200` | Sensor module. Taken. |
| `0x0201–0x02FF` | Further sensor types |
| `0x0300` | Pump module. Taken. |
| `0x0301–0x03FF` | Further types in the pump block |
| `0xF000–0xFFFF` | Experimental |

An id that is not listed in `kModuleTypes` comes online as `Unsupported`. The host health-pings it and sends no type commands. Protocol version 2 of a known id does the same.

## On the board

1. Implement [the contract](contract.md): SENSE, MOD, `0x0A`, `SET_ADDRESS`, `PING`, `GET_IDENTITY`, the 19-byte padded read, and CRC-8/SMBus.
2. Report your type id and protocol version 1 from `GET_IDENTITY`.
3. Implement only your commands. Return `UnknownCmd` for the others. Return `Busy` when the result is not ready. The host will repeat that command.
4. Keep wire indexes 0-based. Report at most 16 channels when the command is indexed. Check a frame against [Frames](frames.md) before looking at a logic analyser.
5. Copy `lib/Interfaces/ModuleProtocol.h` into the daughter project, and add your command bytes there in the controller project in the same change.

Sensor and solenoid boards are an ATmega328PB and use `program N isp`. The pump is an ATtiny1614 and uses `program N updi`. N is the firmware slot the header is jumpered from. See [programming.md](../programming.md).

## On the controller

Follow `lib/Logic/Sensor/`. Four pieces, owned by the module. `main.cpp` does not call the poller or the bridge.

| Piece | Job |
| --- | --- |
| Commands | Encode and decode your payloads. |
| Poller | Per-slot results. At most one `ModuleHost::exchange()` per `update()`. |
| Bridge | Publish from what the poller stored. The MQTT callback only records a request. |
| Module | Owns the poller and the bridge. `update()` runs the poller, then the bridge. |

Then:

1. Add the type id constant next to `kTypeSensorModule` in `ModuleProtocol.h`.
2. Add a row to `kModuleTypes` in `lib/Logic/Bus/SlotController.cpp`. The name in that row is the word in `Online <name> addr=0x1N`. Without the row, the slot stays `Unsupported` and `exchange()` rejects the command.
3. Register an inbound handler in the module constructor when the type has a command topic. Construct the module in `src/main.cpp` before `Network::begin()`. Global constructors already run before `setup()`, which is what the existing three types rely on.
4. Call `update()` from `loop()` after `moduleBus.update()`. Put the poll interval, and any command-absence cutoff, in the timing block of `main.cpp` and pass them in. A zero interval selects the poller's own default. It does not disable the poll.
5. Add the command topic on `MqttTopicLayout` if the broker must deliver one. The layout subscribes to five topics today, all in use (`kSubscriptionCount`). `Network` accepts four handlers (`kMaxInboundHandlers`), and three are in use. A new inbound topic means raising the subscription count. A fourth handler still fits. One handler may serve more than one topic. The sensor bridge and the solenoid bridge do. List the new subscription and its results on [the MQTT reference](../reference/mqtt.md), and on the new type's reference page.
6. Add a desktop test that drives the module through its public `update()`, next to `test/test_desktop/test_sensor.cpp`. Keep any lower-level tests that cover frame edges.
7. Add a short guide next to `docs/sensor-module.md` and a reference page under `docs/reference/`. Link the guide from `docs/home.md` and the reference from `docs/reference/index.md`. State the interval and any absence window on the guide. Name the `main.cpp` constants on the reference page.

`ModuleHost` stays the only I2C caller. The new poller asks it for one exchange. It does not open the bus itself.

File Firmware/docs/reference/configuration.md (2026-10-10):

# Configuration reference

[Home](../home.md) · Guide: [Runtime configuration](../configuration.md)

Source: `lib/Logic/Network/NetworkRuntime.h`, `INetworkConfigStore.h`, `lib/Logic/Console/SerialConfigController.h`.

`NetworkRuntime` is the boundary for network settings. It loads stored fields through `PreferenceNetworkConfigStore` and applies Wi-Fi and MQTT through the services. It owns copies of the active strings, so a staged edit cannot change the active configuration before `apply`. A failed save never changes the active configuration, and the staged fields stay dirty for a retry.

The store contract is in the [network reference](networking.md).

## Commands

`SerialConfigController` accepts complete newline-terminated commands while USB is plugged in:

```text
set wifi.ssid garden
set wifi.password secret
set wifi.hostname plant-room
set status on
set status off
set mqtt.host broker.local
set mqtt.port 1883
set mqtt.client watering-controller
set mqtt.prefix plant-room
set mqtt.username user
set mqtt.password password
apply
status
program 1 isp
program 3 updi
```

`set` updates a staging copy only. `apply` writes just the fields set since the previous successful `apply`, then restarts Wi-Fi when a Wi-Fi field changed and MQTT when an MQTT field changed. A later `set wifi.password` leaves the stored SSID, hostname, status flag, prefix, and broker settings untouched. An empty credential or broker field is a valid stored value. `apply` with nothing newly set replies `OK applied` and does not reconnect. Unknown keys and invalid ports are rejected.

Serial input and responses are suppressed when the USB link is unplugged.

## Fields

| Command | NVS key | Apply restarts | Missing key |
| --- | --- | --- | --- |
| `set wifi.ssid` | `wifi_ssid` | Wi-Fi | Empty string from the defaults in `main.cpp` |
| `set wifi.password` | `wifi_password` | Wi-Fi | Empty string from those defaults |
| `set wifi.hostname` | `wifi_hostname` | Wi-Fi | `watering-controller` from `setup()`, not written until applied |
| `set mqtt.host` | `mqtt_host` | MQTT | Empty string. An empty host stays `Unconfigured` |
| `set mqtt.port` | `mqtt_port` | MQTT | `1883` from the defaults in `main.cpp` |
| `set mqtt.client` | `mqtt_client` | MQTT | `watering-controller`. A stored record that lacks the key prints the warning and saves it |
| `set mqtt.prefix` | `mqtt_prefix` | MQTT | `kMqttDeviceId`, not written |
| `set mqtt.username` | `mqtt_user` | MQTT | Empty until set |
| `set mqtt.password` | `mqtt_password` | MQTT | Empty until set |
| `set status on\|off` | `status_report` | Neither radio | Missing leaves reporting on, not written |

A password-only apply keeps the stored hostname and does not recommit it when it is unchanged. A namespace with none of these keys makes `load` return false. `begin` then keeps the defaults from `main.cpp` and does not write `mqtt_client`. A missing key inside a record that does exist keeps the default in this table.

On boot, a stored record with no `mqtt_client` key uses the built-in client id, prints `Config: mqtt client id is not stored; using <id>`, and saves that id. The built-in id is `watering-controller`. A stored record with no `mqtt_prefix` key keeps `kMqttDeviceId` from `src/main.cpp` and does not write that key.

### Hostname

`set wifi.hostname` stages the DHCP name. A name must be 1–31 characters, use only letters, digits, and hyphens, and start and end with a letter or digit. Anything else replies `ERR hostname` and stages nothing. `apply` stores `wifi_hostname` and reconnects Wi-Fi with that name. The broker settings are left alone. The MQTT session drops with Wi-Fi and reconnects on its own. On boot the station advertises the default instead of the chip MAC name.

Arduino-ESP32 2.0.17 stores the DHCP hostname in a 32-byte buffer, so 31 characters is the maximum it will commit. The commit happens when station mode changes. That is why a hostname apply resets station mode. See the [network reference](networking.md).

### Prefix

`set mqtt.prefix plant-room` stages the device id. This id is the first segment of every topic this board publishes or subscribes to. It uses the hostname rules: 1–31 characters, letters, digits, and hyphens, and it must start and end with a letter or digit. A slash, space, `+`, `#`, empty value, leading or trailing hyphen, or a longer name replies `ERR prefix` and stages nothing. `apply` stores `mqtt_prefix` and restarts MQTT only. Wi-Fi and the MQTT client id are left as they are.

The id used when `mqtt_prefix` is missing is `kMqttDeviceId` in `src/main.cpp`. That constant is `watering`. With the default, the topics stay:

```text
watering/slot/N
watering/slot/N/sensor/M
watering/slot/N/sensors
watering/slot/N/solenoid/M
watering/slot/N/solenoids
watering/slot/N/pump
watering/solenoids
watering/solenoids/connected
watering/pump
watering/sensor/read
watering/sensor/connected
```

`{id}` in the other docs means this segment. After `set mqtt.prefix plant-room` and `apply`, the same tree starts with `plant-room`. The payload for each topic, and a line to publish when testing, are in the [MQTT reference](mqtt.md).

Publishers normally stay quiet once the broker has accepted a payload. Changing the prefix bumps the generation counter in `MqttTopicLayout`, forgets those notes, and publishes the current values once:

```text
plant-room/slot/1                  Online Sensor addr=0x10
plant-room/slot/1/sensor/1         connected 2500
plant-room/slot/1/sensors          2 1
plant-room/slot/1/solenoid/1       on
plant-room/slot/1/solenoids        4 1 2 4
plant-room/slot/1/pump             off
```

The note for each item is written only after the broker accepts that item. During the reconnect, `publish` fails and the note stays clear, so later passes retry. A slot with no sample is still skipped. Commands on the previous prefix are ignored after the change. Retained messages under the old prefix stay on the broker. This firmware does not delete them. The counter itself is described in the [network reference](networking.md).

The hostname, the MQTT client id, and the prefix are three separate settings. When commissioning a board, set all three to the same name:

```text
set wifi.hostname plant-room
set mqtt.client plant-room
set mqtt.prefix plant-room
apply
```

### Status and program

`set status on` and `set status off` stage periodic USB snapshots. `set status maybe` replies `ERR status`. `apply` stores `status_report` as `1` or `0` and then enables or disables periodic printing.

`status` is not a `set` command. It prints one snapshot immediately, including while periodic reporting is off and while a status change is still staged. The snapshot is the seven lines in the [serial console reference](serial-console.md). It does not change the on/off flag. A successful print restarts the wait until the next periodic snapshot.

`program N isp` and `program N updi` reply `OK programming` and a one-line jumper reminder, then hand the USB byte stream to the session in [Programming](../programming.md). N is one digit, 1 through 4. The method word is exactly `isp` or `updi`. The console does not read further lines until that session ends. `program`, `program isp`, `program updi`, `program 1`, `program 1 udpi`, a slot outside 1..4, and any extra token reply `ERR program` and do not start a session. `programmable` is `ERR command`.

## Tests

`test/test_desktop/test_configuration.cpp` uses `FakeNetworkConfigStore` and `FakeSerialPort` for staging, apply, persistence failure, USB plug gating, hostname and prefix rejection, and `program`. `test_mqtt_topics.cpp` covers the generation move. `test_deep_modules.cpp` covers apply through `Network`.

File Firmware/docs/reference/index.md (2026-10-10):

# Reference

[Home](../home.md)

These pages are the technical wiki: states, bytes, errors, timing, and the desktop test that covers them. The short pages one level up say who creates what and what one `update()` does.

## Bus

- [Module bus](module-bus.md) — who holds slot state, the lock, faults, and slot publication.
- [Daughter contract](../daughter/contract.md) — what a board in a slot must answer. Frames are in [daughter/frames.md](../daughter/frames.md).

## Daughter types

- [Sensor](sensor-module.md) — type `0x0200`. Count, presence, readings, immediate read.
- [Solenoid](solenoid-module.md) — type `0x0100`. Count, state, desired on/off, absence cutoff.
- [Pump](pump-module.md) — type `0x0300`. State, on/off, reset, absence cutoff.

## Network and console

- [Network](networking.md) — Wi-Fi, NTP, MQTT, the generation counter, `INetworkConfigStore`.
- [MQTT](mqtt.md) — every subscription and publication, the payload text, and a line to publish when testing.
- [Configuration](configuration.md) — stored fields, `set` / `apply`, topic root.
- [Serial console](serial-console.md) — the seven-line snapshot and plug gating.
- [Programming](programming.md) — ISP or UPDI on slots 1–4, and the RTC latch.

## Ports

- [Hardware interfaces](../interfaces.md) — each port, and what a fake must support.
- `INetworkConfigStore` is documented with [Network](networking.md). It is not a hardware port.

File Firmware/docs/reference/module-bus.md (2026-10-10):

# Module bus reference

[Home](../home.md) · Guide: [Module bus](../module-bus.md)

Source: `lib/Logic/Bus/ModuleBus.h`, `ModuleHost.h`, `SlotController.h`, `ModuleSlotPublisher.h`. The bytes a daughter board answers are in [the daughter contract](../daughter/contract.md) and `lib/Interfaces/ModuleProtocol.h`.

## Purpose

`ModuleBus::update()` runs the host, then the slot publisher. `SlotController` holds one slot. `ModuleHost` owns the four controllers and is the Logic class that calls `I2cMaster`. `ModuleSlotPublisher` turns the public snapshot into retained MQTT text.

## Who holds what

```text
ModuleBus
  owns ModuleHost and ModuleSlotPublisher
  update() = host.update(), then publisher.update()
  begin(), quiesce(), and resume() forward to the host

ModuleHost
  owns SlotController _slots[4]
  owns the enumeration lock (_lockOwner, -1 when free)
  owns the health cursor (_nextHealthSlot)
  readers forward to the matching controller

SlotController
  owns one slot's pins, private phase, and identity fields
  proposes a SlotI2cProposal
  applies the ModuleStepResult the host brings back

ModuleSlotPublisher
  owns the last broker-accepted text, a success flag, and the topic generation
  reads the host; the slot phase stays on the controller
```

Fields on one `SlotController`:

| Field | Meaning |
| --- | --- |
| `_phase` | Private phase. `state()` is the public fold below. |
| `_phaseBeforeAbsent` | Phase to restore if SENSE returns before the absence debounce ends. |
| `_address` | Assigned 7-bit address. Stays 0 until the ping at that address succeeds. |
| `_committedAddress` | Address this slot is using. Set by `SET_ADDRESS`, or by a ping of the slot address after `0x0A` NACKed. Kept when recovery forgets the identity. Cleared when the slot returns to `Empty`. |
| `_priorPublic` | `Online` or `Unsupported` to restore when health recovery finds the assigned address still answering. |
| `_typeId`, `_protocolVersion`, `_firmwareVersion` | Last successful `GET_IDENTITY`. Cleared on return to `Empty`, and when a recovery ping at `0x0A` succeeds. |
| `_identityEpoch` | Count of successful `GET_IDENTITY` results for this slot, including after a restart. |
| `_fault` | Last classified failure, or `None`. |
| `_lockHeld`, `_attempts`, `_healthFails` | Lock flag, tries in the current step, and failed health pings. |
| `_phaseStartedAt`, `_retryAt`, `_lastHealthAt` | Timers for debounce, boot, settle, fault wait, retry gap, and health. |

`targetAddress()` is `0x10 + slotIndex` (slot 1 is `0x10`). `typeName()` is the `kModuleTypes` name when `state()` is `Online` and the protocol is 1, and null otherwise.

Those fields live on the controller. `ModuleHost::state(slot)`, `address(slot)`, and the other readers call that controller. An index outside 0..3 reads as `Empty`, address 0, fault `None`, or a null name.

`ModuleSlotPublisher` keeps `_published[4]` (the last accepted body), `_publishedOk[4]`, and `_seenGeneration`. A failed publish leaves `_publishedOk` false, so the next `update()` tries the same text again. A new topic generation clears the accepted texts.

## Classes

`ModuleBus` exposes `begin`, `update`, `quiesce`, and `resume`. Type modules and the console reach `ModuleHost` through `host()`. `main.cpp` does not call `host()`.

`ModuleHost` exposes `begin`, `update`, `quiesce`, `resume`, the per-slot readers, `enumLockOwner`, `ping`, `echo`, and `exchange`. `exchange` is how a type module sends one command after the bus `update()` has returned. `loop()` drives the slots through `update()`. `ping` and `echo` are direct queries for a caller outside that pass. The publisher calls neither.

`ModuleSlotPublisher::update()` syncs the topic generation, formats each slot with `writeSlotStatusBody`, and publishes when that text is not the last accepted payload. The steps are under [Slot publication](#slot-publication).

One host `update()`, once `begin()` has run and the host is not quiesced:

1. Every controller runs `updatePinsAndState()`. That reads SENSE, debounce, boot wait, MOD settle, and the fault wait. It performs no I2C.
2. `_reconcileLock()` drops the lock when the owner no longer wants it, then grants it to the lowest slot whose `wantsEnumLock()` is true.
3. If the owner proposes an operation other than `None` and other than `HealthPing`, that proposal is the transaction.
4. Otherwise the host walks the slots from `_nextHealthSlot` and takes the first `HealthPing`. The cursor then moves to the following slot.
5. With neither due, `update()` returns. The publisher still runs.
6. `_issue()` performs the one `write` (`SET_ADDRESS`) or `writeRead` (everything else) and classifies it. The controller's `applyI2cResult()` stores the outcome. `_reconcileLock()` runs again.

`Timeout` or `BusError` may call `recover()` once in that same `update()`.

The private phases that want the enumeration lock are `WaitForLock`, `SelectAssert`, `ProbeDefault`, `SetAddress`, `VerifyAssigned`, `Identify`, and the matching `Recover*` phases. `Online` and `Unsupported` propose `HealthPing` and leave the lock free. During MOD settle and the retry gap the owner holds the lock and proposes `None`, so step 4 can still send one health ping.

## Hardware

Firmware slot numbers follow schematic nets and `src/main.cpp` (`SNS1_PIN` is slot 1). Physical left-to-right on the PCB is schematic 4, then 3, then 2, then 1. There is no silkscreen slot number.

| Firmware slot | SENSE | MOD | CS |
| ---: | ---: | ---: | ---: |
| 1 | GPIO39 | GPIO40 | GPIO6 |
| 2 | GPIO41 | GPIO42 | GPIO7 |
| 3 | GPIO44 | GPIO43 | GPIO15 |
| 4 | GPIO2 | GPIO1 | GPIO16 |

Shared I2C is SDA GPIO4 and SCL GPIO5, with 4.7 kΩ pull-ups on the motherboard. Sense uses the ESP32 internal pull-up. The module ties SENSE to GND when seated. LOW means present.

MOD is the enumeration select. The host drives it low to talk to unconfigured address `0x0A`, then releases it to an input. After address assignment a type handler may reuse MOD. Daughter firmware must not require MOD low after `SET_ADDRESS`.

CS is an input with a pull-up, idle HIGH, during normal operation. The module protocol does not use SPI. A programming session can take the selected slot's CS pin as AVR RESET or as the UPDI wire. See [programming.md](../programming.md).

`begin()` sets SENSE to input pull-up, MOD to input, and CS to input pull-up, then starts I2C. GPIO43 and GPIO44 are UART0 pins. The ESP32 driver must call Arduino `pinMode` so that peripheral detaches.

## States

Callers see `SlotState`: `Empty`, `Debouncing`, `Enumerating`, `Online`, `Unsupported`, or `Fault`. The controller stores a finer `Phase`. `state()` maps it like this.

| Private phase | Public `SlotState` |
| --- | --- |
| `Empty` | `Empty` |
| `DebouncePresent` | `Debouncing` |
| `DebounceAbsent` | The public state of `_phaseBeforeAbsent`. A sense gap shorter than the absence debounce leaves the previous public state in place. |
| `BootWait`, `WaitForLock`, `SelectAssert`, `ProbeDefault`, `ProbeAssigned`, `SetAddress`, `VerifyAssigned`, `Identify`, `RecoverWaitLock`, `RecoverSelect`, `RecoverProbeDefault`, `RecoverProbeAssigned` | `Enumerating` |
| `Online` | `Online` |
| `Unsupported` | `Unsupported` |
| `Fault` | `Fault` |

`Debouncing` is the 50 ms presence debounce (`DebouncePresent`). After that, `BootWait` holds the slot in `Enumerating` for 200 ms before it asks for the lock. Slots debounce and boot together. A slot waits for another slot only when it needs the bus.

`GET_IDENTITY` returns a type id, a protocol version, and a firmware version. Protocol version must be 1. The type id is looked up in `kModuleTypes` in `lib/Logic/Bus/SlotController.cpp`. Bands for later boards are listed in [Add a new type](../daughter/new-type.md).

| Identity | Public state | Action for that slot |
| --- | --- | --- |
| `0x0001` IdentityEcho, protocol 1 | `Online` | Health `PING` about once a second. Status text `Online IdentityEcho addr=0x1N`. `ECHO` exists for a caller. `loop()` does not poll it. |
| `0x0100` Solenoid, protocol 1 | `Online` | Health `PING`, plus the commands in the [solenoid reference](solenoid-module.md). Status text `Online Solenoid addr=0x1N`. |
| `0x0200` Sensor, protocol 1 | `Online` | Health `PING`, plus the commands in the [sensor reference](sensor-module.md). Status text `Online Sensor addr=0x1N`. |
| `0x0300` Pump, protocol 1 | `Online` | Health `PING`, plus the commands in the [pump reference](pump-module.md). Status text `Online Pump addr=0x1N`. |
| Any other type id, or a protocol version other than 1 | `Unsupported` | Health `PING` about once a second. Status text `Unsupported type=0xTTTT addr=0x1N`. No type-specific commands. |
| Address assignment or identify keeps failing | `Fault` | No health ping and no type-specific commands. Enumeration is tried again after 1 s. Status text `Fault Nack`, `Fault BadCrc`, `Fault BadFrame`, `Fault Timeout`, or `Fault Busy`. |

`exchange` returns `Ok` with the payload, `Busy` when the module asks for the same command again, `Failed` on a bad frame or a bus error, or `Rejected` when the slot cannot take that command. A `Busy` type-command does not, by itself, move the slot to `Fault`.

## Sequences

Every `ModuleHost::update()` reads SENSE on every slot before any I2C. LOW means present and starts that slot's own debounce. The other slots keep doing what they were doing.

### One enumeration at a time

Unconfigured modules all answer at `0x0A`, so the host selects one slot. The enumeration lock goes to the lowest waiting slot: slot 1 before slot 2, and so on. That slot drives MOD low, waits 10 ms, then:

1. `PING` at `0x0A`.
2. When that ping is answered, `SET_ADDRESS` to `0x10 + slotIndex` (slot 1 is `0x10`, slot 2 is `0x11`), then `PING` at the assigned address, then `GET_IDENTITY`.
3. When `0x0A` NACKs three times, `PING` at `0x10 + slotIndex`. An answer skips `SET_ADDRESS` and goes to `GET_IDENTITY`. Three NACKs enter `Fault`.

The slot address is calculated from the slot index. It is not written to flash. A successful ping stores it in the slot's RAM for this seating. Unplug clears that RAM. The next seating starts again at `0x0A`, which is what a module does after its own power cycle.

The lock stays with that slot until identify finishes and MOD is released. The other module remains `Enumerating` with no address yet. The lock then moves to the next waiting slot. One host transaction runs per `update()`. While the lock owner has an enumeration step due, that step is the transaction. During the 10 ms MOD settle and the 50 ms gap between retries the owner proposes nothing, and one health ping can use the pass. The health ping uses the other slot's assigned address. An unconfigured module under MOD answers at `0x0A`. A module that kept its slot address answers that address.

A seated module that answers neither address is pinged three times at `0x0A` and three times at the slot address, about 50 ms apart, then waits 1 s in `Fault` and repeats from `0x0A`. SENSE can still read present. Those NACKs are not printed by the I2C driver. The console prints `Slot N: Nack` once for that fault. See the [serial console reference](serial-console.md).

### Health

Each online or unsupported slot has its own one-second health timer. The host sends one due health ping per pass and rotates through the slots. Health pings do not take the enumeration lock. Three failed health pings start recovery on that slot. The other slots stay as they are. A sense gap shorter than the 50 ms absence debounce leaves the slot in its current public state.

`Timeout` or `BusError` may call `recover()` once in that same `update()`.

### Two modules plugged in together

A sensor in slot 1 and an IdentityEcho in slot 2:

```text
both slots   Debouncing, then Enumerating, over the same time
slot 1       holds the lock: PING 0x0A, SET_ADDRESS 0x10, PING 0x10, GET_IDENTITY
             Online Sensor addr=0x10
             sensor count, then presence and a reading for each input
slot 2       waits in Enumerating while slot 1 holds the lock
             then the same steps to address 0x11
             Online IdentityEcho addr=0x11
             health pings only
```

Two sensors use that same enumeration. After a slot is online, only that slot starts its type cycle. How those cycles share a poller is described on the type page.

Unplugging slot 2 returns slot 2 to `Empty`. When slot 2 was a sensor, its sensor topics publish retained `unavailable`. Slot 1 keeps its address, its type, and its own cycle.

### Slot publication

`{id}` is the device id from [configuration.md](../configuration.md). It is `watering` until `set mqtt.prefix` is applied. The full command catalog is the [MQTT reference](mqtt.md). This publisher sends the four slot topics and nothing else.

| Topic | Direction | Payload |
| --- | --- | --- |
| `{id}/slot/1` through `{id}/slot/4` | publish, retained, QoS 0 | `writeSlotStatusBody`, for example `Empty` or `Online Sensor addr=0x10` |

`ModuleSlotPublisher` sends those topics after the host has applied this pass's result. It reads the snapshot with `writeSlotStatusBody`. The phase and the identity stay on the slot controller. Each `update()`:

1. Reads `MqttTopicLayout::generation()`. A new value clears `_published` and `_publishedOk` and stores the new generation. The current bodies go out once under the new root. Retained messages under the old prefix are left on the broker.
2. For each slot, calls `writeSlotStatusBody` into an 80-byte buffer (`kSlotStatusBodyBytes`). The body is the serial slot line without the `Slot N:` prefix.
3. Skips the slot when `_publishedOk` is set and the new body matches `_published`.
4. Otherwise publishes the body retained on `{slotPrefix}/{N}`, where firmware index 0 is topic 1. QoS is 0.
5. On success, copies the body into `_published` and sets `_publishedOk`. On failure, leaves the flag clear so the next `update()` retries.

`writeSlotStatusBody` reads `state`, and then the fields that state needs:

| Public state | Payload |
| --- | --- |
| `Online` | `Online {name} addr=0xNN`. `{name}` is `typeName()`, or `Unknown` when that is null. |
| `Unsupported` | `Unsupported type=0xTTTT addr=0xNN` |
| `Fault` | `Fault Nack`, `Fault BadCrc`, `Fault BadFrame`, `Fault Timeout`, or `Fault Busy` |
| `Empty`, `Debouncing`, `Enumerating` | That word alone |

Serial status prints one line per slot from the same function, with a `Slot N:` prefix. Each slot has its own topic. After a reconnect, an accepted body stays unpublished until the text changes.

## Configuration

Defaults in `ModuleHostConfig`:

| Field | Default | Role |
| --- | ---: | --- |
| `presenceDebounceMs` | 50 | Present and absent debounce |
| `bootWaitMs` | 200 | Wait after debounce before the first transaction |
| `modSettleMs` | 10 | MOD low before `PING` at `0x0A` |
| `i2cTimeoutMs` | 50 | Driver timeout for one transaction |
| `i2cClockHz` | 100000 | Bus clock |
| `commandRetries` | 3 | Tries before a fault wait |
| `retryGapMs` | 50 | Gap between those tries |
| `faultRetryMs` | 1000 | Wait in `Fault` before enumerating again |
| `healthPingMs` | 1000 | Per-slot health period |
| `healthFailLimit` | 3 | Failed pings before recovery |

`ModuleProtocol.h` also fixes daughter-side limits the host assumes: MOD gate `kModGateMaxMs` (5 ms) and clock stretch `kClockStretchMaxMs` (40 ms). `main.cpp` passes `ModuleHostConfig{}`, so these defaults are the product timings.

## Tests

- `test/test_desktop/test_modules.cpp` — frames, enumeration, a module that kept its slot address, the lock, faults, `begin` pin modes.
- `test/test_desktop/test_slot_publish.cpp` — retained slot text, retries, prefix generation.
- `test/test_desktop/test_deep_modules.cpp` — `ModuleBus::update()` through the public module, including quiesce.

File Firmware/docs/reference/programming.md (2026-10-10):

# Programming reference

[Home](../home.md) · Guide: [Programming](../programming.md)

Source: `lib/Logic/Programming/Programming.h`, `ProgrammingSession.h`, `IspProgrammer.h`, `UpdiProgrammer.h`. The latch adapter is `lib/Drivers/Esp32ProgrammingLatch.h`. The UPDI UART adapter is `lib/Drivers/Esp32HalfDuplexUart.h`.

## Purpose

The controller is the programmer. Sensor and solenoid modules are an ATmega328PB with a 2×3 ISP header (MISO, VCC, SCK, MOSI, RESET, GND). The pump module is an ATtiny1614 with a UPDI header. Neither header is the slot connector, so the board under test sits off the motherboard and is jumpered from one empty firmware slot.

ISP uses the shared SPI pins plus the selected slot's CS pin as RESET. Remove the other modules, because SPI is one bus. UPDI uses only that slot's CS pin. SPI is not started.

Accepted command lines and `ERR program` are in the [configuration reference](configuration.md).

## Classes

`Programming::begin(slot, method)` selects CS for that slot. ISP calls `IspProgrammer::start`, which drives that pin high as an output. UPDI calls `UpdiProgrammer::start`, which leaves the pin as an input with a pull-up until a break. Both then call `ProgrammingSession::begin`, which quiesces `ModuleBus` and does not drive the pin. A slot outside 1..4 returns before that, so the bus keeps polling. A second `begin` while `active()` is true returns without pulsing reset or attaching the UART.

`update()` services the active programmer until `ProgrammingSession` ends the session. `active()` is what `loop()` branches on. `STK_LEAVE` and jtagice leave do not end the session.

`IspProgrammer` speaks the STK500v1 subset. `UpdiProgrammer` speaks jtag2updi for NVM controller version 1. `ProgrammingSession` owns the silence timer and the unplug rule.

## Pins

GPIO numbers come from `kProgrammingPins` in `src/main.cpp`.

ISP, any slot. The shared nets are the same for every slot. RESET is that slot's CS pin.

| ISP signal | Controller net |
| --- | --- |
| MOSI | GPIO11 |
| MISO | GPIO13 |
| SCK | GPIO12 |
| RESET | Slot 1 GPIO6, slot 2 GPIO7, slot 3 GPIO15, slot 4 GPIO16 |
| VCC | Slot 3.3 V |
| GND | Slot GND |

The console prints that mapping. Slot 3 is:

```text
OK programming
ISP slot 3: MOSI GPIO11, MISO GPIO13, SCK GPIO12, RESET GPIO15, 3V3, GND
```

UPDI, any slot. The single wire is that slot's CS pin. Slot 4 is:

```text
OK programming
UPDI slot 4: UPDI GPIO16, 3V3, GND
```

The slot header is the schematic connector. There is no silkscreen slot number. Physical left-to-right on the board is schematic slot 4 toward slot 1. SPI to every slot is the same bus, with series resistors on the `_R` nets. The ISP clock is 125 kHz, which is slow enough for those resistors.

Power is 3.3 V only. The sensor runs from its internal 8 MHz oscillator, so the ISP clock must stay at or below 2 MHz. This firmware always clocks SPI at 125 kHz. avrdude's `-B5` is accepted and does not change that clock.

Other slots' CS pins stay as they were. Shutdown restores only the claimed CS pin to an input with a pull-up.

## Commands

The host tools, pointed at this controller's COM port:

```text
avrdude -c stk500v1 -P <COM> -b 19200 -B5 -p m328pb
avrdude -c jtag2updi -P <COM> -b 115200 -p t1614
```

Both baud rates are ignored on this USB CDC port. `HWCDC::baudRate()` is fixed at 115200, and USB Serial/JTAG does not expose line coding or break. The double break that enables UPDI is done by this firmware, on the selected CS pin, when avrdude sends the device descriptor. Close the monitor before upload. If the port stays open, avrdude cannot take it.

Build the image first, send the program line, wait until status text stops, close the monitor, and upload within 60 seconds.

## MQTT

Programming subscribes to nothing and publishes nothing. The topics the other modules use are in the [MQTT reference](mqtt.md).

While a session is active, `loop()` still runs `network.update()`, so a command that arrives is recorded by the module that owns it. Slot status and sensor, solenoid, and pump results are published when those modules run again after the session.

## Session

The console prints `OK programming` and the pin line, `loop()` stores the RTC record, and the USB byte stream goes to the programmer. While the session is active, `loop()` updates Wi-Fi, NTP, and MQTT, then the programmer, and returns. It does not read the console, publish slot status, update the sensor, solenoid, or pump modules, or print the heap lines. Desired-state messages can still arrive. They are applied when those modules run again after the session.

Absence timers keep counting. A session longer than `kSolenoidCommandTimeoutMs` (15 minutes) or `kPumpCommandTimeoutMs` (3 minutes) makes the next module update turn those outputs off. A shorter session leaves outputs as they were.

The session ends 60 seconds after the last protocol byte, or 60 seconds after it started when none arrive (`kProgrammingIdleTimeoutMs`). A protocol byte is an STK500 byte or a jtagice frame byte.

After the USB link has been present in this session, it also ends once that link has stayed absent for 1 second (`kProgrammingUnplugTimeoutMs`). The unplug timer arms on the first `update()` while unplugged after the port was seen. Time before that update does not count. A session that has not seen the link yet stays up until the silence timer. A brief re-enumeration gap does not end it.

When the session ends, the claimed CS pin returns to an input with a pull-up. ISP releases SPI. UPDI detaches the UART. The record is cleared, and the normal loop resumes. `loop()` clears the latch and, if `startController()` was skipped, calls it. That prints `Powered on, Initialising..`, the PSRAM line, and `Beginning I2C Communication.` Those lines appear only when a prior reset skipped init. If the command was sent and the chip never reset before the session ended, init already ran and they are not printed again. Ending the session does not reset the chip.

### RTC record

The record is one uninitialized struct in `Esp32ProgrammingLatch`, `RTC_NOINIT_ATTR` in `.rtc_noinit` (NOLOAD) at `0x50000000`. The first field is the magic `0x50524732`. Then a slot byte (1..4), a method byte (1 is ISP, 2 is UPDI), and two reserved bytes. That section is not reloaded from the firmware image, so a USB-open reset or a software restart keeps it. `RTC_DATA_ATTR` is not used: on this SDK it is copied back from its flash image on every restart except deep sleep.

`isSet()` is true only when the magic matches and the slot and method are in range. The older single-word marker `0x49535031` does not match, so a board that still holds that word boots normally.

The reset button pulls `CHIP_PU` low, and a power cycle removes RTC power, so both clear the record. After those, `status` is answered again.

`setup()` enters the stored slot and method when `isSet()` is true, and then returns without the 2 second delay or `startController()`, so that boot prints nothing. Method 2 is UPDI. Method 1 is ISP.

Desktop tests do not cover the `RTC_NOINIT` attribute.

## USB-open restart

avrdude opens the port with DTR/RTS. On this board that reset line is the USB Serial/JTAG controller, so the ESP32 may restart, or the ROM download mode may take the port. The firmware does not add a second USB stack. If the application restarts, setup sees the record, skips the banner, and starts the same programmer before Wi-Fi, NVS, and the banner. The command has already printed `OK programming` before any reset.

If the ROM download mode captures the port, avrdude will not get a sync answer. That has to be checked on the board. Desktop tests do not cover it.

`HWCDC::isPlugged` tracks host start-of-frame, not an open COM application. The plugged confirm is 5 ms. avrdude sync bytes that spell `Free Heap` mean the normal loop is running. Heap lines print every 30 seconds only while the session is inactive.

## ISP sequence

SPI starts first, mode 0, MSB first, SCK idle low, at 125 kHz. Reset (the selected slot's CS pin) is then driven low. After 20 ms the programmer sends `AC 53 00 00`. Success is the third response byte equal to `0x53`. It tries three times. Between tries it pulses reset high, then low, and waits 20 ms again. After three failures it replies STK500 failed and drives reset high as an output.

A second enter, while already programming, replies OK and does not pulse reset. Leave programming ends SPI and drives reset high. The input pull-up is restored when the session ends, not on leave. `ModuleHost::begin()` configures CS only once, so the session restores the pin itself.

Page writes wait 5 ms. Each EEPROM byte waits 10 ms. Chip erase waits 10 ms, including a universal `AC 80 00 00`. The signature is read from the chip. Fuse writes are passed through. A wrong clock fuse can stop ISP until a high-voltage programmer is used.

The spoken protocol is sync, sign-on `AVR ISP`, parameters, device setup, programming enable, universal, paged flash and EEPROM read/write, signature, and chip erase. Unknown commands answer `STK_UNKNOWN` when the next byte is the end marker.

A failed programming enable yields `STK_FAILED` to avrdude with no human-readable line. The physical check is avrdude reporting the device initialized and signature `0x1E9516` (ATmega328PB).

## UPDI sequence

The host frame is jtagice mkII: start `0x1B`, a little-endian sequence, a 4-byte little-endian body size, token `0x0E`, the body, and the AVR067 CRC-16 little-endian. That CRC starts at `0xFFFF` and uses reflected polynomial `0xA001`. The check value of `123456789` is `0x4B37`. The CRC covers the start byte through the last body byte. A bad CRC replies `RSP_FAILED` (`0xA0`) with the received sequence, and the session stays active. An unknown command replies `RSP_ILLEGAL_COMMAND` (`0xAA`). A bad token or a body longer than 512 bytes is dropped with no reply.

`SET_DEVICE_DESCRIPTOR` always starts a double break, including when the link is already up. The selected CS pin is driven open-drain low for 25 ms, high for 1 ms, then low for 25 ms. One phase advances per `update()`. After the second low, the pin is released high and UART1 attaches on that GPIO at 115200, 8 data bits, even parity, 2 stop bits. UART0 is not used: GPIO43 and GPIO44 are MOD3 and SENSE3. The programmer then writes UPDI `Control_A` `0x06`.

`ENTER_PROGMODE` starts the same break when the link is not up yet. Host bytes wait until the break finishes. The status that follows the break selects the NVM key path. A locked part replies `RSP_ILLEGAL_MCU_STATE`. NVM version is 1 when the flash page in the descriptor is under 256 bytes. The ATtiny1614 page is 64. A page of 256 or more is recorded as version 2, and memory commands then fail. Flash addresses are used as avrdude sends them.

The target wire is one byte out and the local echo back before the next byte. A missing echo or a missing target byte fails the command. Leave programming stops driving the line and leaves the UART attached. `shutdown()`, when the session ends, detaches UART1 and restores the CS pull-up.

The physical check is avrdude reporting signature `0x1E9422` (ATtiny1614).

## Configuration

| Constant in `src/main.cpp` | Value | Role |
| --- | --- | --- |
| `kProgrammingIdleTimeoutMs` | 60 seconds | No protocol byte ends the session |
| `kProgrammingUnplugTimeoutMs` | 1 second | Absent frames after the link has been seen |
| `kProgrammingPins` | GPIO11, GPIO13, GPIO12, CS GPIO6 / GPIO7 / GPIO15 / GPIO16 | Pin line and the UPDI GPIO |

ISP SPI is fixed at 125 kHz. UPDI is fixed at 115200 8E2. avrdude's baud parameter does not change either.

## Tests

`test/test_desktop/test_isp.cpp` covers the STK500 subset, the reset-before-SPI order, the fixed 125 kHz clock, the session idle path, an unplug before the port has been seen, a sub-second unplug that leaves the session running, and a full one-second unplug. A second `begin()` after that confirmed unplug starts a new seen-port count.

`test/test_desktop/test_updi.cpp` covers the AVR067 CRC check value, the jtagice sign-on body, the 25/1/25 ms break and `Control_A`, a signature read of `1E 94 22`, chip erase and a 64-byte flash page, a bad CRC, an unknown command, leave versus shutdown, and that the UPDI programmer object does not own an SPI master.

`test/test_desktop/test_deep_modules.cpp` covers slot 3 ISP leaving the other CS pins alone, slot 2 UPDI attaching GPIO7 at 115200 without starting SPI, a second `begin` that does not pulse or reattach, 60 s silence and a seen-then-absent 1 s unplug for both methods, and `begin(0)` / `begin(5)` leaving the bus polling. `test/test_desktop/test_configuration.cpp` covers the accepted lines and `ERR program`.

The `.rtc_noinit` record is ESP32-only. The first check on the board, after a `custom-esp32` build, is that avrdude syncs after the USB-open restart. A 328PB returns `0x1E9516`. An ATtiny1614 returns `0x1E9422`. The controller was not flashed as part of writing this page.

## Errors

| Condition | Result |
| --- | --- |
| Line is not `program N isp` or `program N updi` with N in 1..4 | `ERR program`, no session |
| `begin` with a slot outside 1..4 | Inactive, bus not quiesced |
| Second `begin` while active | No extra reset pulse, no UART reattach |
| ISP programming enable fails three times | `STK_FAILED`, reset left high |
| UPDI CRC mismatch | `RSP_FAILED` (`0xA0`), session stays active |
| UPDI unknown command | `RSP_ILLEGAL_COMMAND` (`0xAA`), session stays active |
| UPDI not in programming mode, or NVM version 2 | Memory command fails, session stays active |
| Missing UPDI echo or target byte | That command fails |
| 60 s with no protocol byte | Session ends, claimed CS returns to pull-up |
| Link seen, then absent for 1 s | Session ends, claimed CS returns to pull-up |

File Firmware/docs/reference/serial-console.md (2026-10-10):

# Serial console reference

[Home](../home.md) · Guide: [Serial console](../serial-console.md)

Source: `lib/Logic/Console/SerialConsole.h`, `SerialConfigController.h`, `SerialStatusReporter.h`.

## Purpose

`update()` reads complete USB lines and dispatches them. `updateStatus()` prints the periodic snapshot after the modules have advanced. `status` calls `printStatus()` inside `update()`, so that snapshot is from before this pass's bus and type modules.

The command grammar is in the [configuration reference](configuration.md). The programming session is in the [programming reference](programming.md).

The console subscribes to nothing and publishes nothing. `MQTT Status:` on the snapshot is the client state, printed on USB. The broker topics are in the [MQTT reference](mqtt.md).

## Classes

`SerialConsole::begin()` starts the reporter at `kSerialStatusIntervalMs` and copies the active `status_report` flag into it. Call it after `Network::begin()`.

`SerialStatusReporter::update()` writes the snapshot when it has been started, periodic reporting is enabled, USB is plugged in, and the interval has elapsed. `printStatus()` writes one snapshot immediately when USB is plugged in, including while periodic reporting is off. A successful immediate print sets the last-report time to now, so the periodic interval starts again from that print.

`setReportingEnabled(true)` also restarts the interval from now. `reconfigure` replaces the interval for the rest of the boot. No USB command calls it. The product interval is the value passed to `begin`.

The reporter reads `WifiManager`, `NtpService`, `MqttService`, and `ModuleHost` snapshots. It must not call `ping()` or `echo()`.

## Snapshot

Seven lines. Connected Wi-Fi with an address other than `0.0.0.0` includes the address and RSSI. Address `0.0.0.0` keeps the RSSI-only line. Other Wi-Fi states omit both. MQTT labels are the `MqttServiceState` names. Unsynchronized NTP omits the time.

```text
WiFi Status: Connected (192.168.1.42, -62 dBm)
NTP Status: Synchronized (2026-09-21 16:04:00)
MQTT Status: Connected
Slot 1: Empty
Slot 2: Online IdentityEcho addr=0x11
Slot 3: Unsupported type=0x02AA addr=0x12
Slot 4: Fault Nack
```

Wi-Fi forms:

```text
WiFi Status: Connected (192.168.1.42, -62 dBm)
WiFi Status: Connected (-62 dBm)
WiFi Status: Connecting
```

NTP forms:

```text
NTP Status: Synchronized (YYYY-MM-DD HH:MM:SS)
NTP Status: WaitingForSync
```

Local time is the UTC epoch plus `NtpConfig` `utcOffsetSeconds` and `daylightOffsetSeconds`, formatted 24-hour. Logic does not call Arduino `localtime()`. Time is omitted unless the service is `Synchronized`.

`Connecting` is a real MQTT state and is usually not visible after `MqttService::update()` returns. The other labels are `Idle`, `Unconfigured`, `WaitingForNetwork`, `Connected`, and `Backoff`.

Firmware slot 1 is index 0 and address `0x10`. Slot text is the same body `ModuleSlotPublisher` uses, with a `Slot N:` prefix. The body itself is in the [module bus reference](module-bus.md).

Heap and PSRAM lines are printed from `loop()` in `main.cpp` every `kMemoryReportIntervalMs` (30 seconds) when USB is plugged in. They are not part of this snapshot, and they are not printed while a programming session is active.

## Sequences

Input and both prints are suppressed when `ISerialPort::isPlugged()` is false. On the ESP32 that is the USB CDC plug state, which tracks host start-of-frame, not an open COM application.

`status` does not change the on/off flag and does not change the interval length. `set status on` and `set status off` are staged. They take effect on `apply`, which stores `status_report` as 1 or 0 in the network namespace and then calls `setReportingEnabled`. A missing key leaves reporting on and is not written until applied. `status` still prints while a status change is staged and not yet applied.

The interval stays in session RAM. Reboot restores `kSerialStatusIntervalMs` (10 seconds) from `setup()` via `begin`. No command stores a different interval.

## Errors

Lines that are not a known command are rejected by `SerialConfigController`. The reply strings (`ERR hostname`, `ERR prefix`, `ERR status`, `ERR program`, `OK applied`) are in the [configuration reference](configuration.md).

`printStatus()` writes nothing when USB is unplugged.

A slot in `Fault Nack` prints `Slot N: Nack` once from `updateStatus()`, including while periodic reporting is off. The following snapshot still contains `Slot N: Fault Nack`. The short line is not printed again until the slot has been `Empty`, `Online`, or `Unsupported`. A snapshot that already includes the fault counts as the one report, so the short line is skipped on that pass. USB unplugged prints neither. An I2C NACK is not printed by the driver.

## Configuration

| Constant in `src/main.cpp` | Value | Role |
| --- | --- | --- |
| `kSerialStatusIntervalMs` | 10 seconds | Periodic snapshot. Not stored |
| `kMemoryReportIntervalMs` | 30 seconds | Heap and PSRAM lines in `loop()` |

## Tests

`test/test_desktop/test_status.cpp` pins the epoch and offsets and covers plug gating, interval spacing, `begin`, `reconfigure`, MQTT state labels, slot lines, and time advancing after sync. `test_configuration.cpp` covers `set`, `apply`, `status`, and `program`. `test_deep_modules.cpp` drives the console through `SerialConsole`.

Snapshots in tests are seven lines. The reporter is constructed with an empty module host when the test has no bus of its own.

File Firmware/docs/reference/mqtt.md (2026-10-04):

# MQTT reference

[Home](../home.md) · Guide: [Network](../networking.md)

Source: `lib/Logic/Network/MqttTopicLayout.h`, `MqttService.h`. Payloads are built in `ModuleSlotPublisher`, `SlotStatusText`, `SensorMqttBridge`, `SolenoidMqttBridge`, and `PumpMqttBridge`.

This page is the command catalog. It lists every subscription and every publication, the payload text, and a line you can publish to test. When a command is applied, the poll order, and the absence windows stay on the module reference. If a page and the firmware disagree, the firmware wins. Update this page and that module page together.

`{id}` is the topic root. It is `kMqttDeviceId` in `src/main.cpp` (`watering`) until `set mqtt.prefix` is applied. The examples below use `watering`. Replace that segment when the prefix is something else.

## Purpose

`MqttTopicLayout` builds five QoS 1 subscriptions. `MqttService` subscribes after the broker connection succeeds, and it stays connected only when every subscribe succeeds. Sensor, solenoid, and pump each register one handler. The sensor handler serves both sensor topics. The solenoid handler serves both solenoid topics.

Outbound publishes are QoS 0. `IMqttClient::publish` has no QoS argument, and `PubSubClient`'s publish sets the retain bit only.

Publish a command with retain off. A retained command is delivered again each time the controller subscribes.

## Find a command

| You want | Publish to | Payload | Result arrives on |
| --- | --- | --- | --- |
| One sensor reading | `{id}/sensor/read` | `1 2` | `{id}/slot/1/sensor/2` |
| Which sensor inputs are connected | `{id}/sensor/connected` | `1` | `{id}/slot/1/sensors` |
| Desired state of every solenoid output | `{id}/solenoids` | `1 on on off off` | `{id}/slot/1/solenoid/1` and the other outputs |
| Which solenoid outputs are connected | `{id}/solenoids/connected` | `1` | `{id}/slot/1/solenoids` |
| Pump on, off, or reset | `{id}/pump` | `1 on` | `{id}/slot/1/pump` |
| Whether a slot has a board, and which type | — | the controller publishes this | `{id}/slot/1` through `{id}/slot/4` |

Slot numbers in every payload are 1..4. Slot 1 is I2C `0x10`, slot 2 is `0x11`, slot 3 is `0x12`, slot 4 is `0x13`. Sensor and solenoid indexes in topics and in connected-list results are 1-based.

To learn a count before naming every output, publish the connected-list command and read the first number of the result.

Watch the whole tree, then publish one command:

```text
mosquitto_sub -h <broker> -t watering/# -v
mosquitto_pub -h <broker> -t watering/sensor/read -q 1 -m "1 2"
```

`<broker>` is `mqtt.host`. The port default is `1883`. `mosquitto_pub` leaves retain off unless `-r` is passed. `-q 1` matches the subscription. The controller does not read the inbound QoS.

A new subscriber receives the last retained result from the broker. The controller sends that result again when a new sample is stored, or when the text changes, or when the command asks for the list again.

## Subscriptions

All five are QoS 1. They are not stored in NVS. `set mqtt.prefix` rebuilds the list under the new root.

| Topic | Payload | Handler |
| --- | --- | --- |
| `{id}/solenoids` | `N on off ...` | Solenoid bridge |
| `{id}/solenoids/connected` | `N` | Solenoid bridge, same handler |
| `{id}/pump` | `N on`, `N off`, or `N reset` | Pump bridge |
| `{id}/sensor/read` | `N M` | Sensor bridge |
| `{id}/sensor/connected` | `N` | Sensor bridge, same handler |

Words are lowercase. Separators are spaces or tabs. Leading and trailing spaces and tabs are accepted. A `+`, a sign, a decimal point, or an empty payload is ignored. An ignored command publishes nothing.

`N` is the slot, 1..4. `M` is the sensor, 1..16. `0` and a slot above 4 are ignored. A sensor number above 16 is ignored.
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

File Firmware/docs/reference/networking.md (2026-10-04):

# Network reference

[Home](../home.md) · Guide: [Network](../networking.md)

Source: `lib/Logic/Network/Network.h`, `WifiManager.h`, `NtpService.h`, `MqttService.h`, `MqttTopicLayout.h`, `NetworkRuntime.h`, `INetworkConfigStore.h`.

`main.cpp` does not call the classes below. Construction, `begin`, `apply`, and the handler fan-out are covered through `Network` in `test_deep_modules.cpp`. The state machines keep their own tests.
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

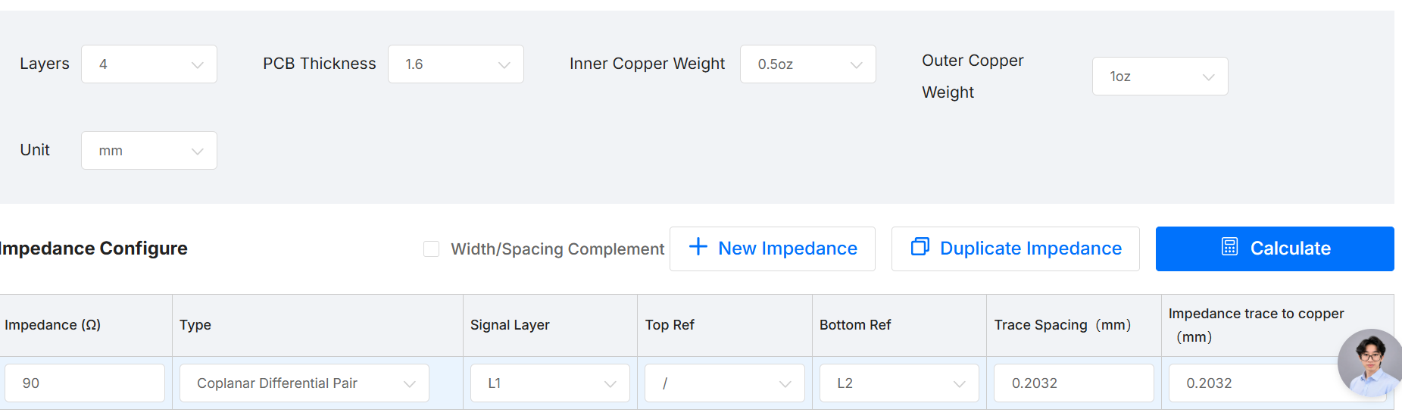
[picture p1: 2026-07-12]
References/Impedance_Config.png

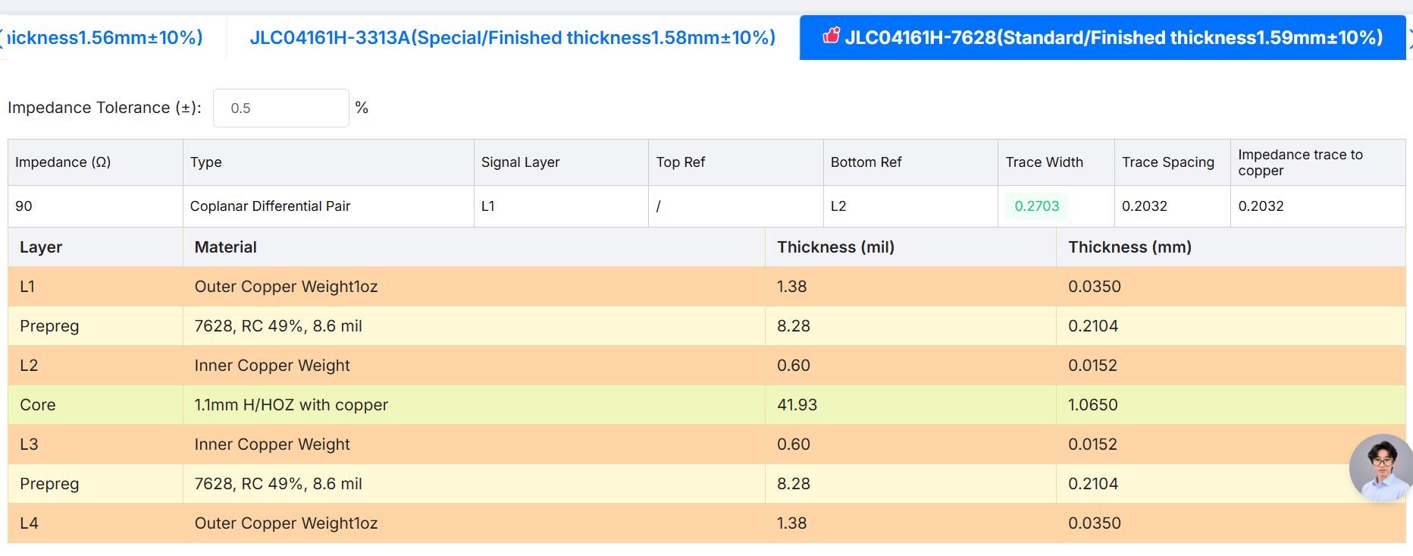
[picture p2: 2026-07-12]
References/Impedance_Selection.png

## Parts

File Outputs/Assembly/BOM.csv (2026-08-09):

# | Qty | Reference | Value | Manufacturer | Manufacturer Part No | JLCPCB Part # | Package | Footprint
1 | 11 | C201,C302,C303,C304,C305,C306,C307,C402,C405,C412,C417 | 10uF 10% 25V | Samsung Electro-Mechanics | CL31A106KAHNNNE | C9807 | 1206 | JLCPCB Basic:CAPC3216X180N
2 | 1 | C202 | 1uF 10% 50V | Samsung Electro-Mechanics | CL21B105KBFNNNE | C28323 | 0805 | JLCPCB Basic:CAPC2012X135N
3 | 9 | C203,C204,C205,C301,C308,C401,C403,C413,C416 | 0.1uF 10% 50V | YAGEO | CC0603KRX7R9BB104 | C14663 | 0603 | JLCPCB Basic:CAPC1608X90N
4 | 1 | C208 | 22pF 5% 50V | Samsung Electro-Mechanics | CL10C220JB8NNNC | C1653 | 0603 | JLCPCB Basic:CAPC1608X90N
5 | 2 | C309,C415 | 220nF 10% 50V | Samsung Electro-Mechanics | CL21B224KBFNNNE | C5378 | 0805 | JLCPCB Basic:CAPC2012X135N
6 | 1 | C414 | 47uF 20% 10V | Samsung Electro-Mechanics | CL31A476MPHNNNE | C96123 | 1206 | JLCPCB Basic:CAPC3216X190N
7 | 1 | D303 | 13V 21.5V 1uA Leak | Littelfuse | SMBJ13CA | C224008 | DO-214AA | LITTELFUSE Diodes:DO-214AA_Bidirectional
8 | 1 | D401 | KT-0603R | Hubei KENTO Elec | KT-0603R | C2286 | 0603 | JLCPCB Basic:LED_0603_1608Metric
9 | 1 | D601 | 40V 1A | Guangdong Hottech | 1N5819WS | C191023 | SOD-323 | GUANGDONG HOTTECH Diodes:D_SOD-323F
10 | 2 | IC301,IC403 | LM74700QDBVTQ1 | Texas Instruments | LM74700QDBVTQ1 | C2653623 | SOT-23-6 | TEXAS INSTRUMENTS ICs:SOT95P280X145-6N
11 | 1 | IC401 | TLV76733DRVR | Texas Instruments | TLV76733DRVR | C2848334 | WSON-6(2x2) | TEXAS INSTRUMENTS ICs:SON65P200X200X80-7N
12 | 1 | J301 | 1715721 | Phoenix Contact | 1715721 | C480516 | Plugin,P=5.08mm | PHOENIX CONTACT Terminals:1715721
13 | 8 | J501,J502,J503,J504,J505,J506,J507,J508 | A2541HWV-10P | CJT(Changjiang Connectors) | A2541HWV-10P | C225507 | Plugin,P=2.54mm | CJT Connectors:PinSocket_1x10_P2.54mm_Vertical_Female
14 | 1 | J601 | 1051640001 | MOLEX | 1051640001 | C234179 | SMD | MOLEX Connectors:CON00906_5_MOL
15 | 1 | L402 | 10uH, 5.4A, 20% | SXN(Shun Xiang Nuo Elec) | SMDRI127-100MT | C9904 | SMD,12.3x12.3mm | Inductor_SMD:L_SXN_SMDRI127
16 | 1 | PS401 | TPS54308DDCR | Texas Instruments | TPS54308DDCR | C168839 | SOT-23-6 | TEXAS INSTRUMENTS ICs:SOT95P280X110-6N
17 | 2 | Q301,Q402 | 60V 38A | onsemi | NVD5C684NLT4G | C236252 | DPAK | ONSEMI Transistors:DPAK__SINGLE-GAUGE__TO-252_369C__ISSUE_F
18 | 6 | R201,R202,R203,R204,R205,R206 | 10kΩ 1/8W 1% | UNI-ROYAL(Uniroyal Elec) | 0805W8F1002T5E | C17414 | 0805 | JLCPCB Basic:RESC2013X65N
19 | 2 | R207,R208 | 22Ω 1/8W 5% | UNI-ROYAL(Uniroyal Elec) | 0805W8F220JT5E | C17561 | 0805 | JLCPCB Basic:RESC2013X65N
20 | 2 | R209,R210 | 4.7kΩ 1/8W 1% | UNI-ROYAL(Uniroyal Elec) | 0805W8F4701T5E | C17673 | 0805 | JLCPCB Basic:RESC2013X65N
21 | 3 | R211,R212,R213 | 47Ω 1/8W 1% | UNI-ROYAL(Uniroyal Elec) | 0805W8F470JT5E | C17714 | 0805 | JLCPCB Basic:RESC2013X65N
22 | 1 | R401 | 330Ω 1/8W 1% | UNI-ROYAL(Uniroyal Elec) | 0805W8F3300T5E | C17630 | 0805 | JLCPCB Basic:RESC2013X65N
23 | 3 | R405,R601,R602 | 100kΩ 1/8W 1% | UNI-ROYAL(Uniroyal Elec) | 0805W8F1003T5E | C149504 | 0805 | JLCPCB Basic:RESC2013X65N
24 | 1 | R406 | 13.7kΩ 1/8W 1% | YAGEO | AC0805FR-0713K7L | C228298 | 0805 | YAGEO Resistors:RESC2012X60N
25 | 2 | S201,S202 | Push Button SPST | XUNPU | TS-1088-AR02016 | C720477 | SMD,4x3mm | JLCPCB Basic:SW_TS-1088-AR02016
26 | 1 | U201 | ESP32-S3-WROOM-1U-N16R8 | Espressif Systems | ESP32-S3-WROOM-1U-N16R8 | C3013946 | SMD,19.2x18mm | ESPRESSIF Microcontrollers:ESP32-S3-WROOM-1U
27 | 1 | U601 | ESD Protection IC | STMicroelectronics | USBLC6-2SC6 | C7519 | SOT-23-6L | STMICROELECTRONICS Protection:SOT95P280X145-6N

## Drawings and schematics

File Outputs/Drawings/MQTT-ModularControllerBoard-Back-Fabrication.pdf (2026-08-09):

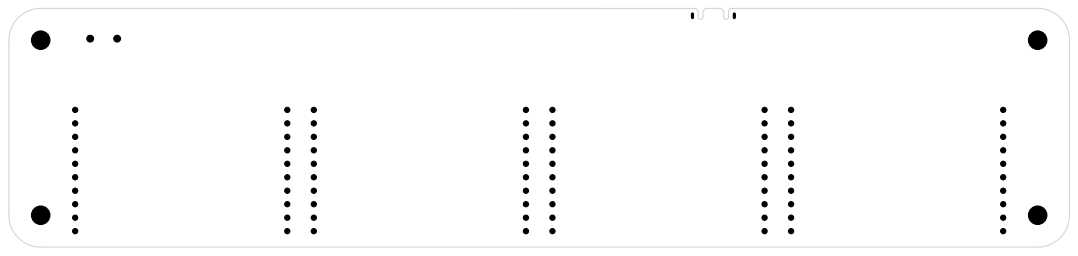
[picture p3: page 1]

File: MQTT-ModularControllerBoard.kicad_pcb Sheet:
Id: 1/1 Title: MQTT ModularControllerBoard

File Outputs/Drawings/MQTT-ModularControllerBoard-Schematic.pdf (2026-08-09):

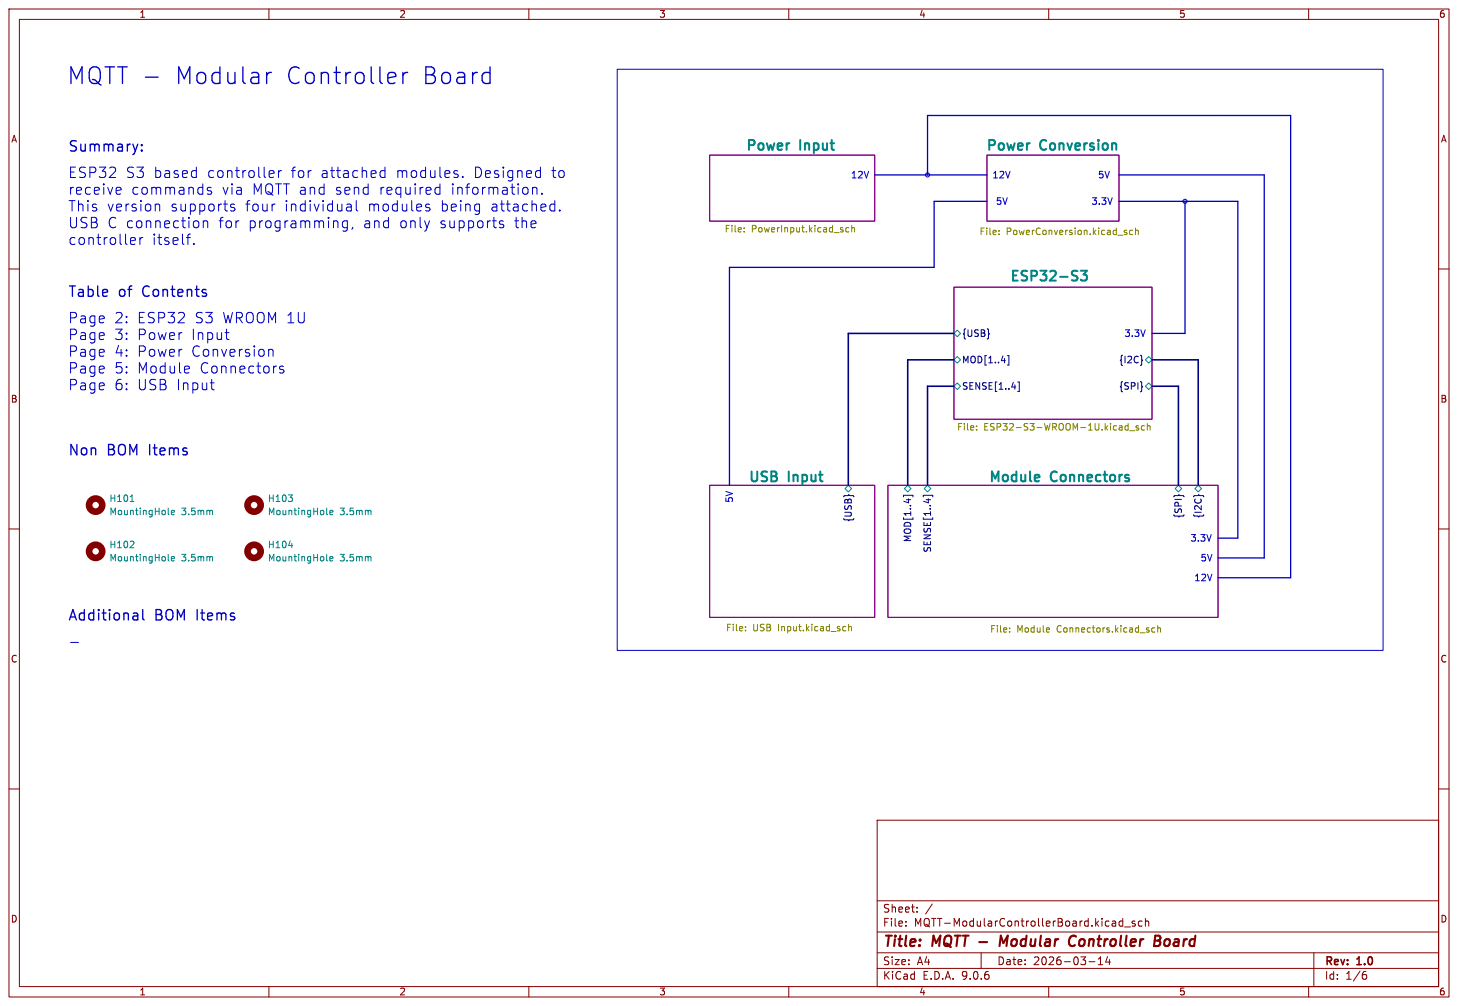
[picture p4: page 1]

12V MQTT - Modular Controller Board

File: MQTT-ModularControllerBoard.kicad_sch Sheet: / {USB}

Id: 1/6 Title: MQTT - Modular Controller Board

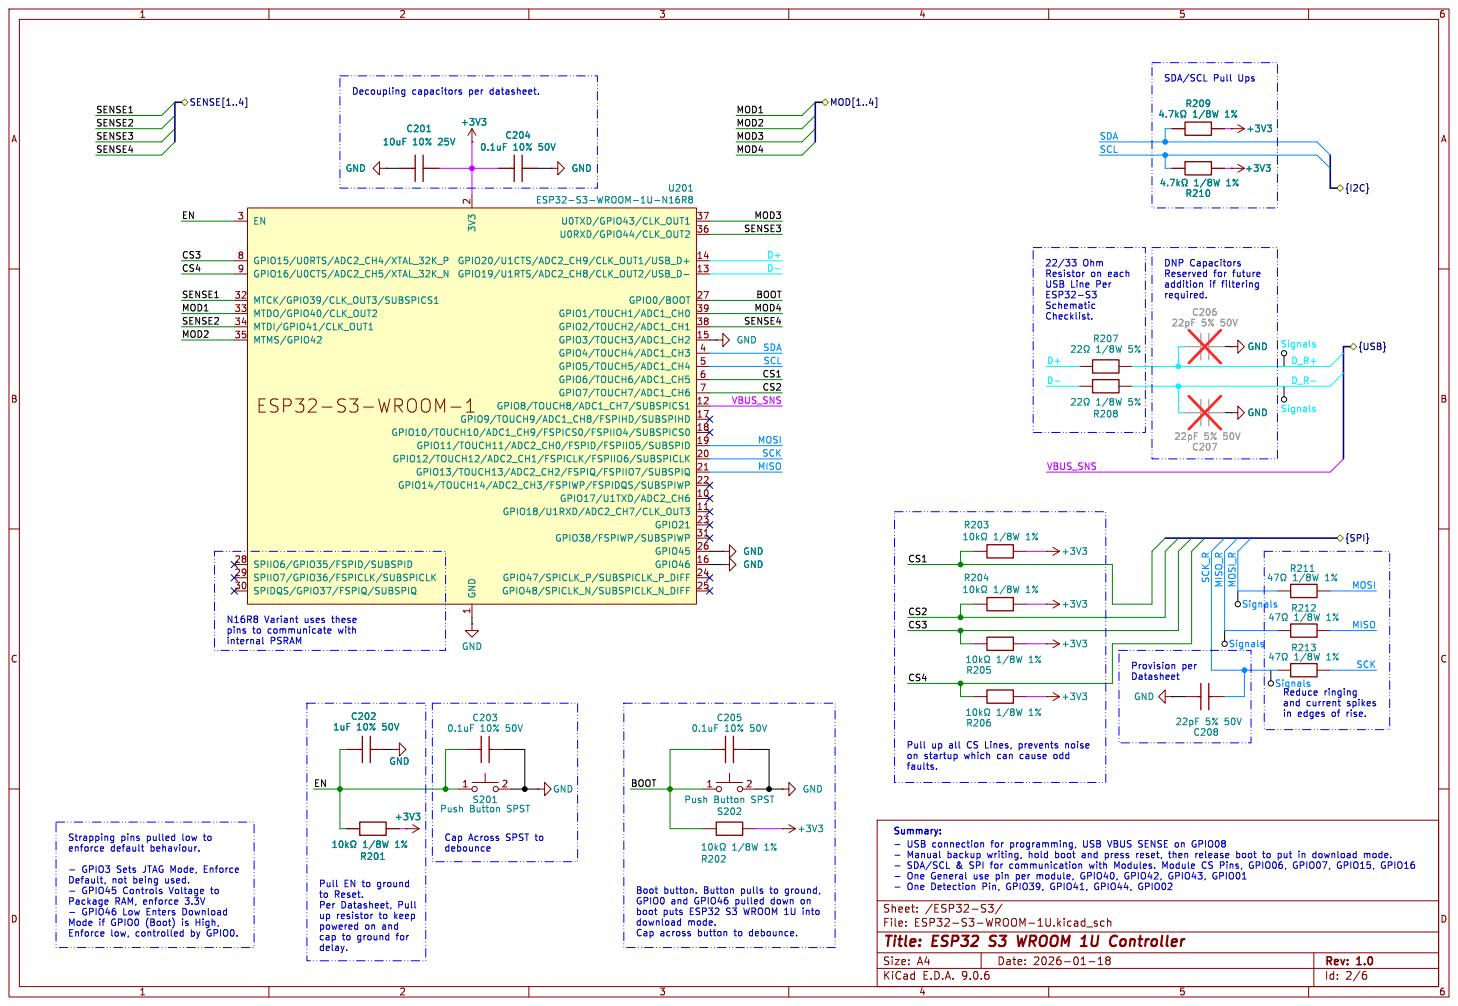
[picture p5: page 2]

SDA/SCL Pull Ups
GND
Resistor on each USB Line Per ESP32-S3 Schematic Checklist. Pull up all CS Lines, prevents noise

1 U0TXD/GPIO43/CLK_OUT1 37 U0RXD/GPIO44/CLK_OUT2 36 GPIO20/U1CTS/ADC2_CH9/CLK_OUT1/USB_D+ 14 GPIO19/U1RTS/ADC2_CH8/CLK_OUT2/USB_D- 13 GPIO0/BOOT 27 GPIO1/TOUCH1/ADC1_CH0 39 GPIO2/TOUCH2/ADC1_CH1 38 GPIO3/TOUCH3/ADC1_CH2 15 GPIO4/TOUCH4/ADC1_CH3 4 GPIO5/TOUCH5/ADC1_CH4 5 GPIO6/TOUCH6/ADC1_CH5 6 GPIO7/TOUCH7/ADC1_CH6 7 GPIO8/TOUCH8/ADC1_CH7/SUBSPICS1 12 GPIO9/TOUCH9/ADC1_CH8/FSPIHD/SUBSPIHD 17 GPIO10/TOUCH10/ADC1_CH9/FSPICS0/FSPIIO4/SUBSPICS0 18 GPIO11/TOUCH11/ADC2_CH0/FSPID/FSPIIO5/SUBSPID 19 GPIO12/TOUCH12/ADC2_CH1/FSPICLK/FSPIIO6/SUBSPICLK 20 GPIO13/TOUCH13/ADC2_CH2/FSPIQ/FSPIIO7/SUBSPIQ 21 GPIO14/TOUCH14/ADC2_CH3/FSPIWP/FSPIDQS/SUBSPIWP 22 GPIO17/U1TXD/ADC2_CH6 10 GPIO18/U1RXD/ADC2_CH7/CLK_OUT3 11 GPIO21 23 GPIO38/FSPIWP/SUBSPIWP 31 GPIO45 26 GPIO46 16 GPIO47/SPICLK_P/SUBSPICLK_P_DIFF 24 GPIO48/SPICLK_N/SUBSPICLK_N_DIFF 25 U201 ESP32-S3-WROOM-1U-N16R8 R210

required. Boot button. Button pulls to ground, GPIO0 and GPIO46 pulled down on

debounce N16R8 Variant uses these

in edges of rise. Cap Across SPST to

on startup which can cause odd

faults. Summary: Pull EN to ground

- One General use pin per module, GPIO40, GPIO42, GPIO43, GPIO01

Id: 2/6 Title: ESP32 S3 WROOM 1U Controller File: ESP32-S3-WROOM-1U.kicad_sch Sheet: /ESP32-S3/

boot puts ESP32 S3 WROOM 1U into

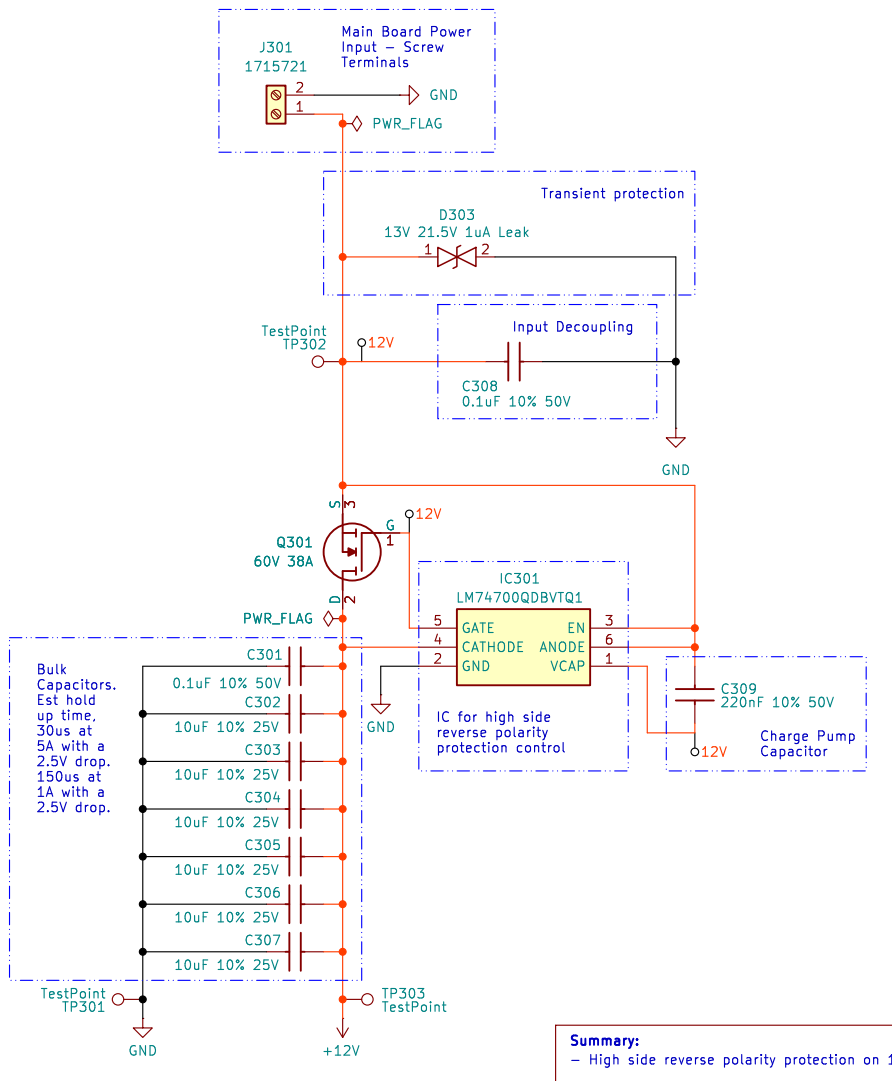
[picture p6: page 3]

Input Decoupling Transient protection

up time, 30us at 5A with a

IC for high side
reverse polarity

Id: 3/6 Title: Power Input & Protection

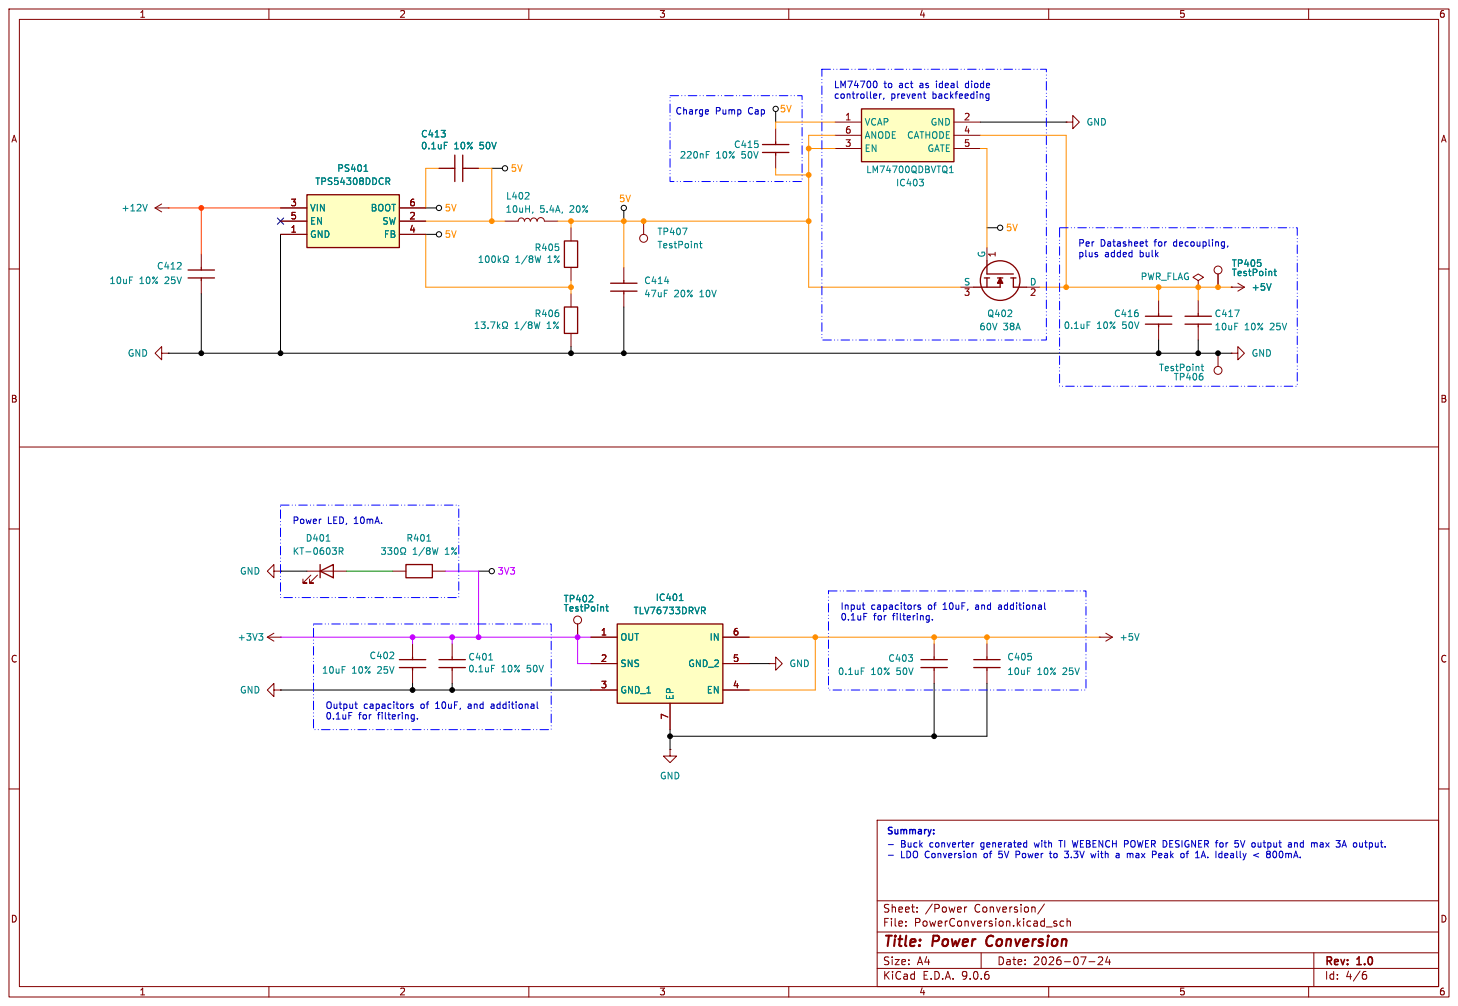
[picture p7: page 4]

LM74700 to act as ideal diode

Id: 4/6 Title: Power Conversion

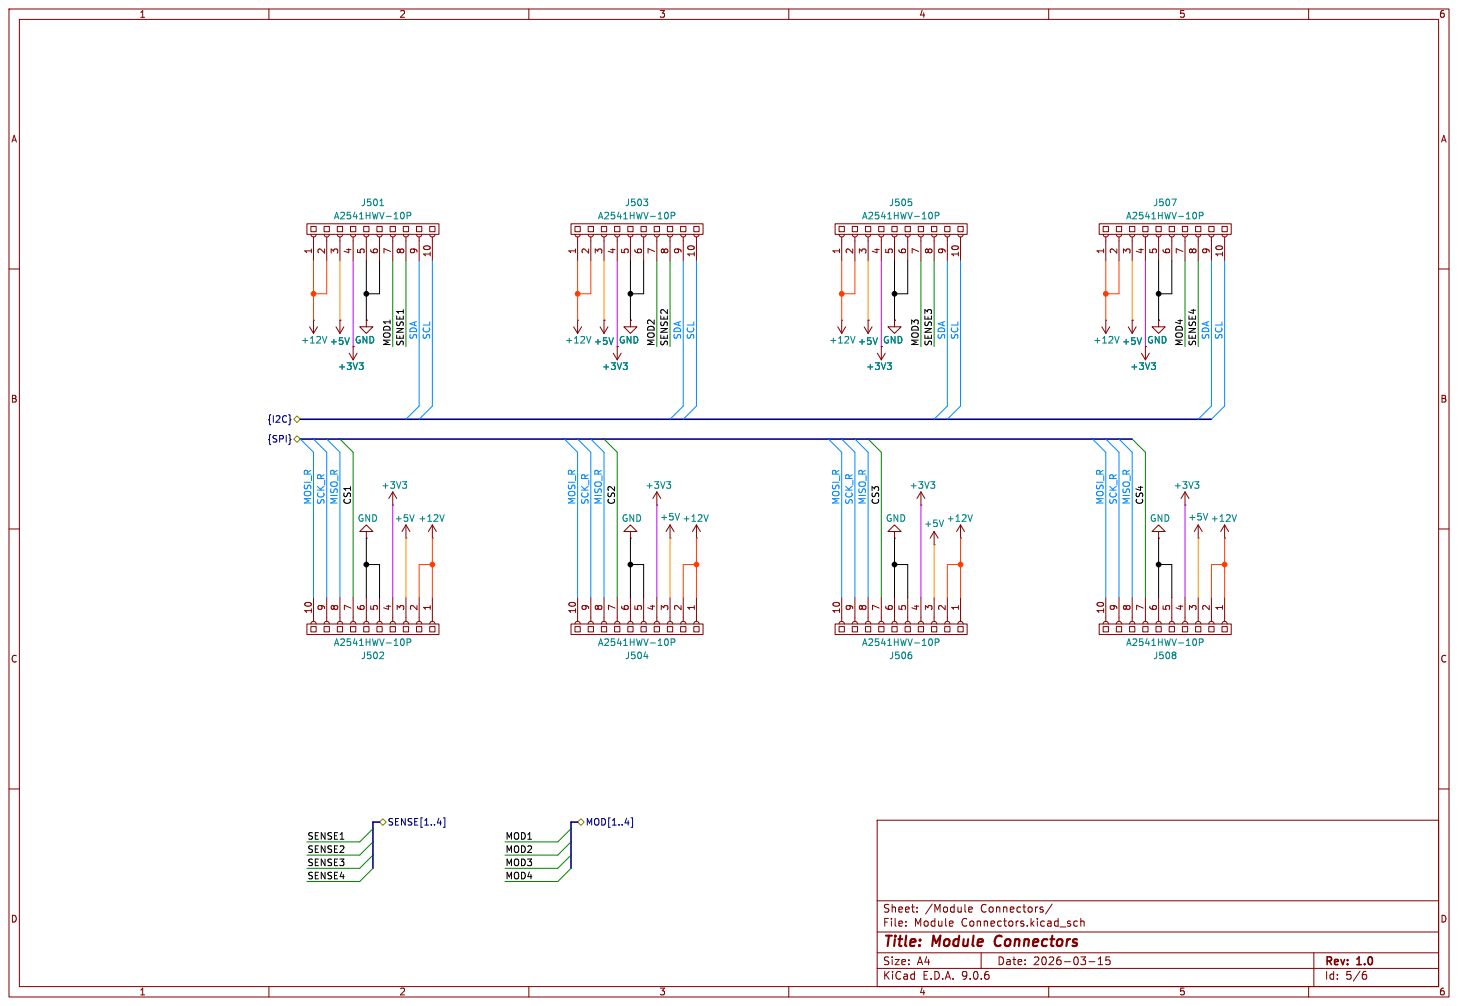
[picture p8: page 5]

Id: 5/6 Title: Module Connectors

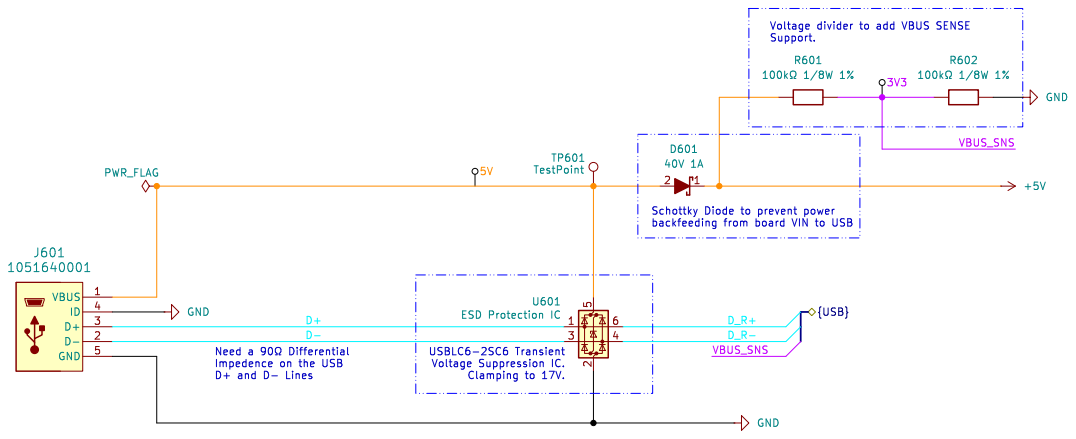
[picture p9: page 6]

Voltage divider to add VBUS SENSE

Id: 6/6 Title: USB C Connection

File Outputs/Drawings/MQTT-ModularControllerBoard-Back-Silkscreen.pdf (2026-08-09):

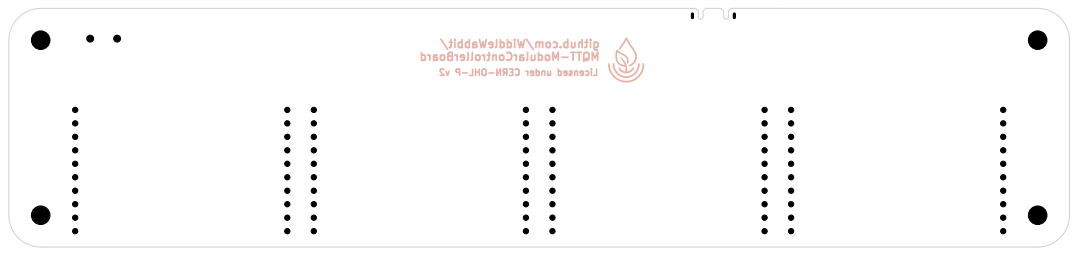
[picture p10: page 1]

File: MQTT-ModularControllerBoard.kicad_pcb Sheet:
Id: 1/1 Title: MQTT ModularControllerBoard

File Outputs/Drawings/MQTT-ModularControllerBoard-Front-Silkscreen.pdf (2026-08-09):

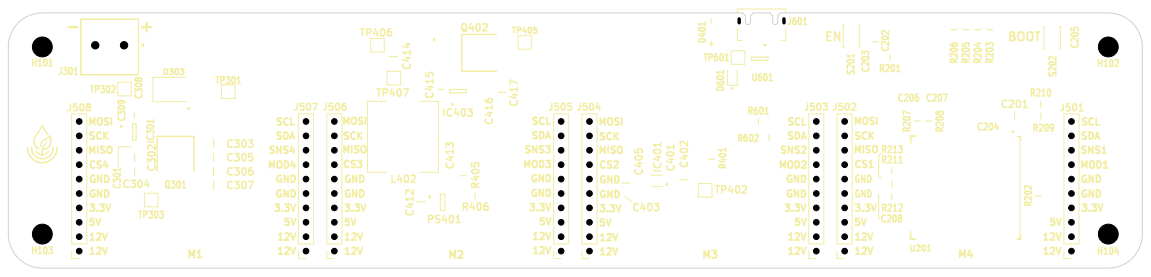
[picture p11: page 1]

File: MQTT-ModularControllerBoard.kicad_pcb Sheet: GND

Id: 1/1 Title: MQTT ModularControllerBoard

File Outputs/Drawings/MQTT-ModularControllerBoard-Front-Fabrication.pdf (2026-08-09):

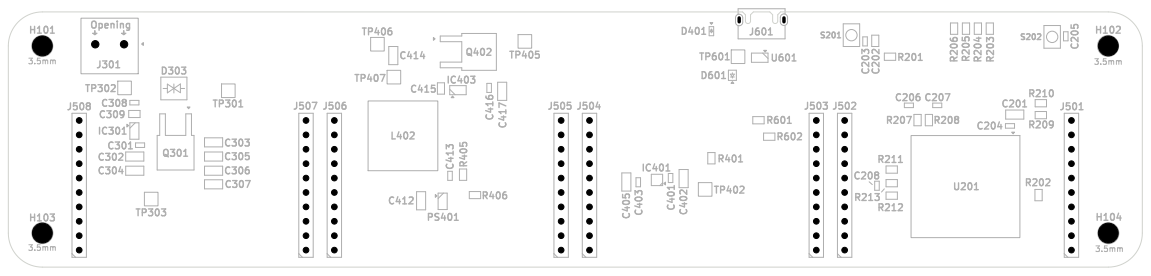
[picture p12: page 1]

Id: 1/1 Title: MQTT ModularControllerBoard

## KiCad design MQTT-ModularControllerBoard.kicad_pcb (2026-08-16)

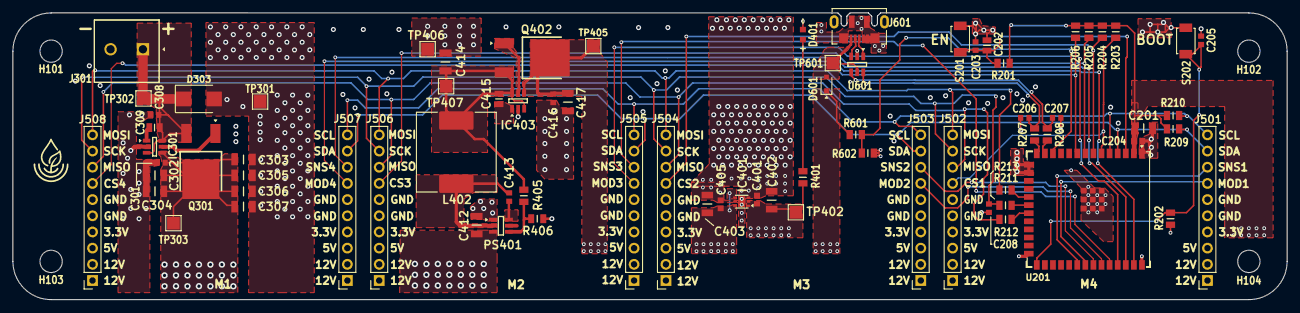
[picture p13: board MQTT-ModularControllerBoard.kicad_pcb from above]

Board: 4 copper layers, 200.0 x 45.0 mm, 81 parts (0 on the bottom side), 44 nets.

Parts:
C201, C302, C303, C304, C305, C306, C307, C402, C405, C412, C417: 10uF 10% 25V; CAPC3216X180N
C202: 1uF 10% 50V; CAPC2012X135N
C203, C204, C205, C301, C308, C401, C403, C413, C416: 0.1uF 10% 50V; CAPC1608X90N
C206, C207, C208: 22pF 5% 50V; CAPC1608X90N
C309, C415: 220nF 10% 50V; CAPC2012X135N
C414: 47uF 20% 10V; CAPC3216X190N
D303: 13V 21.5V 1uA Leak; DO-214AA_Bidirectional
D401: KT-0603R; LED_0603_1608Metric
D601: 40V 1A; D_SOD-323F
H101, H102, H103, H104: 3.5mm; MountingHole_3.5mm
IC301, IC403: LM74700QDBVTQ1; SOT95P280X145-6N
IC401: TLV76733DRVR; SON65P200X200X80-7N
J301: 1715721
J501, J502, J503, J504, J505, J506, J507, J508: A2541HWV-10P; PinSocket_1x10_P2.54mm_Vertical_Female
J601: 1051640001; CON00906_5_MOL
L402: 10uH, 5.4A, 20%; L_SXN_SMDRI127
PS401: TPS54308DDCR; SOT95P280X110-6N
Q301, Q402: 60V 38A; DPAK__SINGLE-GAUGE__TO-252_369C__ISSUE_F
R201, R202, R203, R204, R205, R206: 10kΩ 1/8W 1%; RESC2013X65N
R207, R208: 22Ω 1/8W 5%; RESC2013X65N
R209, R210: 4.7kΩ 1/8W 1%; RESC2013X65N
R211, R212, R213: 47Ω 1/8W 1%; RESC2013X65N
R401: 330Ω 1/8W 1%; RESC2013X65N
R405, R601, R602: 100kΩ 1/8W 1%; RESC2013X65N
R406: 13.7kΩ 1/8W 1%; RESC2012X60N
S201, S202: Push Button SPST; SW_TS-1088-AR02016
TP301, TP302, TP303, TP402, TP405, TP406, TP407, TP601: TestPoint; TestPoint_Pad_2.0x2.0mm
U201: ESP32-S3-WROOM-1U-N16R8; ESP32-S3-WROOM-1U
U601: ESD Protection IC; SOT95P280X145-6N

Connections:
+3V3: C201.2, C204.1, C401.1, C402.2, IC401.1 (OUT), IC401.2 (SNS), J501.4, J502.4, J503.4, J504.4, J505.4, J506.4, J507.4, J508.4, R201.1, R202.2, R203.2, R204.2, R205.2, R206.2, R209.2, R210.2, R401.2, TP402.1, U201.2 (3V3)
+5V: C403.1, C405.2, C416.2, C417.2, D601.1 (K), IC401.4 (EN), IC401.6 (IN), IC403.4 (CATHODE), J501.3, J502.3, J503.3, J504.3, J505.3, J506.3, J507.3, J508.3, Q402.2 (D), R601.1, TP405.1
+12V: C301.2, C302.2, C303.2, C304.2, C305.2, C306.2, C307.2, C412.2, IC301.4 (CATHODE), J501.1, J501.2, J502.1, J502.2, J503.1, J503.2, J504.1, J504.2, J505.1, J505.2, J506.1, J506.2, J507.1, J507.2, J508.1, J508.2, PS401.3 (VIN), Q301.2 (D), TP303.1
/ESP32-S3/BOOT: C205.1, R202.1, S202.1, U201.27 (GPIO0/BOOT)
/ESP32-S3/CS1: J502.7, R203.1, U201.6 (GPIO6/TOUCH6/ADC1_CH5)
/ESP32-S3/CS2: J504.7, R204.1, U201.7 (GPIO7/TOUCH7/ADC1_CH6)
/ESP32-S3/CS3: J506.7, R205.1, U201.8 (GPIO15/U0RTS/ADC2_CH4/XTAL_32K_P)
/ESP32-S3/CS4: J508.7, R206.1, U201.9 (GPIO16/U0CTS/ADC2_CH5/XTAL_32K_N)
/ESP32-S3/D+: R207.1, U201.14 (GPIO20/U1CTS/ADC2_CH9/CLK_OUT1/USB_D+)
/ESP32-S3/D-: R208.1, U201.13 (GPIO19/U1RTS/ADC2_CH8/CLK_OUT2/USB_D-)
/ESP32-S3/D_R+: C206.2, R207.2, U601.6 (I/O1)
/ESP32-S3/D_R-: C207.2, R208.2, U601.4 (I/O2)
/ESP32-S3/EN: C202.2, C203.1, R201.2, S201.1, U201.3 (EN)
/ESP32-S3/MISO: R212.1, U201.21 (GPIO13/TOUCH13/ADC2_CH2/FSPIQ/FSPIIO7/S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)
/ESP32-S3/MISO_R: J502.8, J504.8, J506.8, J508.8, R212.2
/ESP32-S3/MOD1: J501.7, U201.33 (MTDO/GPIO40/CLK_OUT2)
/ESP32-S3/MOD2: J503.7, U201.35 (MTMS/GPIO42)
/ESP32-S3/MOD3: J505.7, U201.37 (U0TXD/GPIO43/CLK_OUT1)
/ESP32-S3/MOD4: J507.7, U201.39 (GPIO1/TOUCH1/ADC1_CH0)
/ESP32-S3/MOSI: R211.1, U201.19 (GPIO11/TOUCH11/ADC2_CH0/FSPID/FSPIIO5/S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)
/ESP32-S3/MOSI_R: J502.10, J504.10, J506.10, J508.10, R211.2
/ESP32-S3/SCK: R213.1, U201.20 (GPIO12/TOUCH12/ADC2_CH1/FSPICLK/FSPIIO6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)
/ESP32-S3/SCK_R: C208.1, J502.9, J504.9, J506.9, J508.9, R213.2
/ESP32-S3/SCL: J501.10, J503.10, J505.10, J507.10, R210.1, U201.5 (GPIO5/TOUCH5/ADC1_CH4)
/ESP32-S3/SDA: J501.9, J503.9, J505.9, J507.9, R209.1, U201.4 (GPIO4/TOUCH4/ADC1_CH3)
/ESP32-S3/SENSE1: J501.8, U201.32 (MTCK/GPIO39/CLK_OUT3/SUBSPICS1)
/ESP32-S3/SENSE2: J503.8, U201.34 (MTDI/GPIO41/CLK_OUT1)
/ESP32-S3/SENSE3: J505.8, U201.36 (U0RXD/GPIO44/CLK_OUT2)
/ESP32-S3/SENSE4: J507.8, U201.38 (GPIO2/TOUCH2/ADC1_CH1)
/ESP32-S3/VBUS_SNS: R601.2, R602.1, U201.12 (GPIO8/TOUCH8/ADC1_CH7/SUBSPICS1)
/USB Input/D+: J601.3 (D+), U601.1 (I/O1)
/USB Input/D-: J601.2 (D-), U601.3 (I/O2)
GND: C201.1, C202.1, C203.2, C204.2, C205.2, C206.1, C207.1, C208.2, C301.1, C302.1, C303.1, C304.1, C305.1, C306.1, C307.1, C308.2, C401.2, C402.1, C403.2, C405.1, C412.1, C414.1, C416.1, C417.1, D303.2 (A2), D401.1 (K), IC301.2 (GND), IC401.3 (GND_1), IC401.5 (GND_2), IC401.7 (EP), IC403.2 (GND), J301.2, J501.5, J501.6, J502.5, J502.6, J503.5, J503.6, J504.5, J504.6, J505.5, J505.6, J506.5, J506.6, J507.5, J507.6, J508.5, J508.6, J601.4 (ID), J601.5 (GND), J601.6 (GND), PS401.1 (GND), R406.1, R602.2, S201.2, S202.2, TP301.1, TP406.1, U201.1 (GND), U201.15 (GPIO3/TOUCH3/ADC1_CH2), U201.16 (GPIO46), U201.26 (GPIO45), U201.40 (GND), U201.41 (GND), U601.2 (GND)
unnamed: C308.1, C309.1, D303.1 (A1), IC301.3 (EN), IC301.6 (ANODE), J301.1, Q301.3 (S), TP302.1
unnamed: D401.2 (A), R401.1
unnamed: D601.2 (A), J601.1 (VBUS), TP601.1, U601.5 (VBUS)
unnamed: IC301.5 (GATE), Q301.1 (G)
unnamed: C309.2, IC301.1 (VCAP)
unnamed: C414.2, C415.2, IC403.3 (EN), IC403.6 (ANODE), L402.2, Q402.3 (S), R405.2, TP407.1
unnamed: IC403.5 (GATE), Q402.1 (G)
unnamed: C415.1, IC403.1 (VCAP)
unnamed: C413.2, PS401.6 (BOOT)
unnamed: PS401.4 (FB), R405.1, R406.2
unnamed: C413.1, L402.1, PS401.2 (SW)

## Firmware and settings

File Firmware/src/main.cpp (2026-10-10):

#include <Arduino.h>
#include <PubSubClient.h>
#include <WiFi.h>
#include <Wire.h>

#include "Esp32Clock.h"
#include "Esp32DigitalPin.h"
#include "Esp32HalfDuplexUart.h"
#include "Esp32I2cMaster.h"
#include "Esp32NtpAdapter.h"
#include "Esp32PreferenceStore.h"
#include "Esp32ProgrammingLatch.h"
#include "Esp32SerialPort.h"
#include "Esp32SpiMaster.h"
#include "Esp32Wifi.h"
#include "ModuleBus.h"
#include "Network.h"
#include "Programming.h"
#include "PubSubClientAdapter.h"
#include "PumpModule.h"
#include "SensorModule.h"
#include "SerialConsole.h"
#include "SolenoidModule.h"

// ========== Timing ==========

// Presence and a raw reading for each sensor input repeat on this period.
// Three failed count queries wait this long before the count is tried again.
const uint32_t kSensorPollIntervalMs = 60UL * 1000UL;

// State of each solenoid output is read and published on this period.
const uint32_t kSolenoidPollIntervalMs = 60UL * 1000UL;

// Accepted solenoid commands must arrive within this window.
// After 15 minutes with none, every solenoid output is turned off.
const uint32_t kSolenoidCommandTimeoutMs = 15UL * 60UL * 1000UL;

// State of the pump is read and published on this period.
const uint32_t kPumpPollIntervalMs = 60UL * 1000UL;

// Accepted pump on/off commands must arrive within this window.
// After 3 minutes with none, a pump that is on is turned off.
// A reset command does not refresh this window.
const uint32_t kPumpCommandTimeoutMs = 3UL * 60UL * 1000UL;

// USB serial status snapshot. Reboot restores this; it is not stored.
const uint32_t kSerialStatusIntervalMs = 10UL * 1000UL;

// Heap and PSRAM lines on the USB serial port.
const uint32_t kMemoryReportIntervalMs = 30UL * 1000UL;

// No protocol byte for this long ends the programming session and
// resumes the module host. Solenoid and pump absence windows keep counting.
const uint32_t kProgrammingIdleTimeoutMs = 60UL * 1000UL;

// After the USB link has been seen, this long with no frames ends the
// programming session. A monitor close or open can stop frames for less
// than this.
const uint32_t kProgrammingUnplugTimeoutMs = 1000UL;

const NetworkTiming kNetworkTiming = {15000, 1000, 30000, 1000, 30000};

const NtpConfig kNtpConfig = {
  "pool.ntp.org", "time.nist.gov", nullptr, 28800, 0, 60000};


// ========== Network ==========

// Topic root used when mqtt_prefix is not stored. One path segment.
const char kMqttDeviceId[] = "watering";

Esp32Clock systemClock;
Esp32Wifi wifiDriver;
Esp32NtpAdapter ntpDriver;
WiFiClient mqttTransport;
PubSubClient pubSubClient(mqttTransport);
PubSubClientAdapter mqttDriver(pubSubClient);
Esp32PreferenceStore networkPreferences("network");
Network network(wifiDriver, ntpDriver, mqttDriver, systemClock,
                networkPreferences, kMqttDeviceId, kNtpConfig, kNetworkTiming);


// ========== Board pins ==========

const uint8_t SDA_PIN = 4;
const uint8_t SCL_PIN = 5;
const uint8_t MOSI_PIN = 11;
const uint8_t MISO_PIN = 13;
const uint8_t SCK_PIN = 12;
const uint8_t CS1_PIN = 6;
const uint8_t CS2_PIN = 7;
const uint8_t CS3_PIN = 15;
const uint8_t CS4_PIN = 16;
const uint8_t SNS1_PIN = 39;
const uint8_t SNS2_PIN = 41;
const uint8_t SNS3_PIN = 44;
const uint8_t SNS4_PIN = 2;
const uint8_t MOD1_PIN = 40;
const uint8_t MOD2_PIN = 42;
const uint8_t MOD3_PIN = 43;
const uint8_t MOD4_PIN = 1;

Esp32DigitalPin sns1(SNS1_PIN);
Esp32DigitalPin sns2(SNS2_PIN);
Esp32DigitalPin sns3(SNS3_PIN);
Esp32DigitalPin sns4(SNS4_PIN);
Esp32DigitalPin mod1(MOD1_PIN);
Esp32DigitalPin mod2(MOD2_PIN);
Esp32DigitalPin mod3(MOD3_PIN);
Esp32DigitalPin mod4(MOD4_PIN);
Esp32DigitalPin cs1(CS1_PIN);
Esp32DigitalPin cs2(CS2_PIN);
Esp32DigitalPin cs3(CS3_PIN);
Esp32DigitalPin cs4(CS4_PIN);


// ========== Modules ==========

Esp32I2cMaster i2cMaster(Wire, SDA_PIN, SCL_PIN);
SlotPins slotPins[4] = {
  {sns1, mod1, cs1},
  {sns2, mod2, cs2},
  {sns3, mod3, cs3},
  {sns4, mod4, cs4},
};
ModuleBus moduleBus(i2cMaster, systemClock, slotPins, ModuleHostConfig{},
                    network);
SensorModule sensorModule(moduleBus, network, systemClock,
                          kSensorPollIntervalMs);
SolenoidModule solenoidModule(moduleBus, network, systemClock,
                              kSolenoidPollIntervalMs,
                              kSolenoidCommandTimeoutMs);
PumpModule pumpModule(moduleBus, network, systemClock, kPumpPollIntervalMs,
                      kPumpCommandTimeoutMs);


// ========== Serial console and programming ==========

Esp32SerialPort serialPort(Serial);
const ProgrammingPins kProgrammingPins = {
  MOSI_PIN, MISO_PIN, SCK_PIN, {CS1_PIN, CS2_PIN, CS3_PIN, CS4_PIN}};
SerialConsole serialConsole(serialPort, systemClock, network, moduleBus,
                            kSerialStatusIntervalMs, kProgrammingPins);
Esp32SpiMaster ispSpi(SCK_PIN, MISO_PIN, MOSI_PIN);
Esp32HalfDuplexUart updiUart;
Esp32ProgrammingLatch programmingLatch;
Programming programming(serialPort, ispSpi, updiUart, cs1, cs2, cs3, cs4,
                        kProgrammingPins, moduleBus, systemClock,
                        kProgrammingIdleTimeoutMs,
                        kProgrammingUnplugTimeoutMs);
bool startupAttempted = false;


/**
 * Starts PSRAM, the module bus, and network services once.
 * A programming session that began from the RTC latch calls this
 * after the session ends. A failed PSRAM init does not try again.
 *
 * @return Nothing.
 */
void startController()
{
  startupAttempted = true;

  if (serialPort.isPlugged())
  {
    Serial.println();
    Serial.println("Powered on, Initialising..");
  }

  if (psramInit())
  {
    if (serialPort.isPlugged())
    {
      Serial.println("PSRAM initialized");
      Serial.print("Memory available in PSRAM : ");
      Serial.println(static_cast<unsigned long>(ESP.getFreePsram()));
    }
  }
  else
  {
    if (serialPort.isPlugged())
    {
      Serial.println("PSRAM not found or initialization failed");
    }
    return;
  }

  if (serialPort.isPlugged())
  {
    Serial.println("Beginning I2C Communication.");
  }
  moduleBus.begin();

  network.begin(
    {"", "", "", 1883, "watering-controller", nullptr, nullptr,
     "watering-controller", true, kMqttDeviceId});
  if (serialPort.isPlugged())
  {
    const char* warning = network.loadWarning();
    if (warning != nullptr && warning[0] != '\0')
    {
      Serial.println(warning);
    }
  }
  serialConsole.begin();
}


/**
 * Opens USB serial. A latched programming session starts immediately
 * so an avrdude port-open restart reaches the programmer before the
 * banner delay.
 *
 * @return Nothing.
 */
void setup()
{
  Serial.begin(115200);
  if (programmingLatch.isSet())
  {
    const ProgrammingMethod method = programmingLatch.method() == 2
                                       ? ProgrammingMethod::Updi
                                       : ProgrammingMethod::Isp;
    programming.begin(programmingLatch.slot(), method);
    return;
  }
  delay(2000);
  startController();
}


/**
 * One pass of the controller. Network always runs. While a programming
 * session is active the USB byte stream belongs to ISP or UPDI, and the
 * module bus, daughter modules, and status lines wait. Otherwise the
 * console reads commands, the bus takes at most one I2C transaction,
 * and each daughter module takes at most one exchange and publishes
 * what it stored. The periodic USB snapshot is last.
 *
 * @return Nothing.
 */
void loop()
{
  // Advance Wi-Fi, NTP, and MQTT. Inbound commands are queued here.
  // Idle until startController(), including during a latched session.
  network.update();

  if (programming.active())
  {
    // Programming session only. No console lines, I2C, modules, or status.
    programming.update();
    if (programming.active())
    {
      return;
    }
    programmingLatch.clear();
    if (!startupAttempted)
    {
      startController();
    }
  }

  // Read complete USB serial lines (set, apply, status, program).
  serialConsole.update();
  ProgrammingRequest request;
  if (serialConsole.takeProgrammingRequest(request))
  {
    // Store the latch before the session so a USB restart re-enters.
    programmingLatch.set(request.slot, static_cast<uint8_t>(request.method));
    programming.begin(request.slot, request.method);
    return;
  }

  // At most one I2C transaction, then slot status if its text changed.
  moduleBus.update();
  // At most one sensor exchange, then publish what it stored.
  sensorModule.update();
  // At most one solenoid exchange, then publish what it stored.
  solenoidModule.update();
  // At most one pump exchange, then publish what it stored.
  pumpModule.update();

  // Print Wi-Fi, NTP, MQTT, and the four slot lines when the snapshot
  // interval has elapsed and USB is plugged in.
  serialConsole.updateStatus();

  // Print free heap and PSRAM when USB is plugged in.
  static uint32_t lastReportAt = 0;
  const uint32_t now = systemClock.millis();
  if (static_cast<uint32_t>(now - lastReportAt) >= kMemoryReportIntervalMs)
  {
    lastReportAt = now;
    if (serialPort.isPlugged())
    {
      Serial.print("Free Heap Memory: ");
      Serial.println(static_cast<unsigned long>(ESP.getFreeHeap()));
      Serial.print("Free PSRAM: ");
      Serial.println(static_cast<unsigned long>(ESP.getFreePsram()));
    }
  }

  delay(10);
}

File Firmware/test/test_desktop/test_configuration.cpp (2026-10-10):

#include <string>

#include <unity.h>

#include "NetworkConfigRecord.h"
#include "NetworkRuntime.h"
#include "NtpService.h"
#include "ProgrammingTarget.h"
#include "SerialConfigController.h"
#include "SerialStatusReporter.h"
#include "fakes/EmptyModuleHostFixture.h"
#include "fakes/FakeClock.h"
#include "fakes/FakeMqttClient.h"
#include "fakes/FakeNetworkConfigStore.h"
#include "fakes/FakeNtpAdapter.h"
#include "fakes/FakePreferenceStore.h"
#include "fakes/FakeSerialPort.h"
#include "fakes/FakeWifi.h"

namespace
{
const ProgrammingPins kProgrammingPins = {11, 13, 12, {6, 7, 15, 16}};

NetworkConfig config()
{
  return {"old", "oldpw", "old-broker", 1883, "controller", nullptr, nullptr,
          nullptr, false, "watering"};
}

WifiManagerConfig wifiConfig()
{
  return {"old", "oldpw", 1000, 100, 400};
}

MqttConfig mqttConfig()
{
  return {"controller", nullptr, nullptr, nullptr, 0, 100, 400};
}

struct CommandStack
{
  FakeNetworkConfigStore store;
  FakeClock clock;
  EmptyModuleHostFixture modules;
  FakeWifi wifi;
  FakeNtpAdapter ntpAdapter;
  FakeMqttClient mqttClient;
  FakeSerialPort serial;
  WifiManager wifiManager;
  NtpService ntpService;
  MqttService mqttService;
  MqttTopicLayout topics;
  NetworkRuntime runtime;
  SerialStatusReporter reporter;
  SerialConfigController controller;

  CommandStack()
    : modules(clock),
      wifiManager(wifi, clock, wifiConfig()),
      ntpService(ntpAdapter, clock,
                 {"pool.ntp.org", "time.nist.gov", nullptr, 0, 0, 60000}),
      mqttService(mqttClient, clock, mqttConfig()),
      topics("watering"),
      runtime(store, wifiManager, mqttService, topics),
      reporter(serial, clock, wifiManager, ntpService, mqttService,
               modules.host),
      controller(serial, runtime, reporter, kProgrammingPins)
  {
    const NetworkConfig defaults = {
      "old", "oldpw", "old-broker", 1883, "controller", nullptr, nullptr,
      "watering-controller", true, "watering"};
    runtime.begin(defaults);
    reporter.begin({1000});
    reporter.setReportingEnabled(runtime.config().statusReporting);
  }
};
}

void testRuntimeLoadsPersistedConfiguration()
{
  FakeNetworkConfigStore store;
  store.seed({"saved", "pw", "broker", 1884, "id", "u", "p"});
  FakeClock clock;
  FakeWifi wifi;
  FakeMqttClient client;
  WifiManager wifiManager(wifi, clock, wifiConfig());
  MqttService mqtt(client, clock, mqttConfig());
  MqttTopicLayout topics("watering");
  NetworkRuntime runtime(store, wifiManager, mqtt, topics);

  TEST_ASSERT_TRUE(runtime.begin(config()));
  TEST_ASSERT_EQUAL_STRING("saved", runtime.config().wifiSsid);
  TEST_ASSERT_EQUAL_STRING("saved", wifiManager.config().ssid);
}

void testSerialStagesUntilApplyAndGatesOnPlugState()
{
  FakeNetworkConfigStore store;
  FakeClock clock;
  FakeWifi wifi;
  FakeMqttClient client;
  WifiManager wifiManager(wifi, clock, wifiConfig());
  MqttService mqtt(client, clock, mqttConfig());
  MqttTopicLayout topics("watering");
  NetworkRuntime runtime(store, wifiManager, mqtt, topics);
  runtime.begin(config());
  FakeSerialPort serial;
  EmptyModuleHostFixture modules(clock);
  FakeNtpAdapter ntpAdapter;
  NtpService ntpService(ntpAdapter, clock,
                        {"pool.ntp.org", nullptr, nullptr, 0, 0, 60000});
  SerialStatusReporter reporter(serial, clock, wifiManager, ntpService, mqtt,
                                modules.host);
  SerialConfigController controller(serial, runtime, reporter, kProgrammingPins);

  serial.feed("set wifi.ssid new-network\n");
  controller.update();
  TEST_ASSERT_EQUAL_STRING("old", runtime.config().wifiSsid);
  TEST_ASSERT_EQUAL(0, store.saveCallCount);

  serial.feed("apply\n");
  controller.update();
  TEST_ASSERT_EQUAL_STRING("new-network", runtime.config().wifiSsid);
  TEST_ASSERT_EQUAL(1, store.saveCallCount);

  serial.plugged = false;
  serial.feed("set mqtt.host hidden\napply\n");
  controller.update();
  TEST_ASSERT_EQUAL_STRING("new-network", runtime.config().wifiSsid);
  TEST_ASSERT_EQUAL(1, store.saveCallCount);

  serial.plugged = true;
  controller.update();
  TEST_ASSERT_EQUAL_STRING("hidden", runtime.config().mqttHost);
  TEST_ASSERT_EQUAL(2, store.saveCallCount);
}

void testRuntimeApplyFailureDoesNotChangeActiveConfiguration()
{
  FakeNetworkConfigStore store;
  FakeClock clock;
  FakeWifi wifi;
  FakeMqttClient client;
  WifiManager wifiManager(wifi, clock, wifiConfig());
  MqttService mqtt(client, clock, mqttConfig());
  MqttTopicLayout topics("watering");
  NetworkRuntime runtime(store, wifiManager, mqtt, topics);
  runtime.begin(config());
  store.saveResult = false;

  NetworkConfig replacement = {"new", "pw", "host", 1883, "id", nullptr, nullptr,
                              "plant-room", true};
  TEST_ASSERT_FALSE(runtime.apply(replacement, NetworkConfigFieldMask::all()));
  TEST_ASSERT_EQUAL_STRING("old", runtime.config().wifiSsid);
}
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

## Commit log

2026-07-08 Update PCB stackup information in README
    Added details about JLCPCB impedance control stackup.
2026-07-08 Revise README description for clarity
    Updated the description to clarify the board's functionality and communication methods.
2026-07-08 Minor fixes to notes on schematics
    [ESP32-S3-WROOM-1U.kicad_sch]
2026-07-08 Added Copyright notice to board.
    [MQTT-ModularControllerBoard.kicad_pcb]
2026-07-11 Minor tweaking, increased spacing on close Via's, ensured star routing pattern on a couple of components.
    [MQTT-ModularControllerBoard.kicad_pcb]
2026-07-11 Updated symbols, added jobset and output folders.
    [ESP32-S3-WROOM-1U.kicad_sch, PowerConversion.kicad_sch, PowerInput.kicad_sch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]
2026-07-12 Recalculated and reran the USB Lines and impedance. Updated symbols to work in BOM. Ran output.
    [BOM.csv, JLC_BOM.csv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]
2026-07-13 Updated inductor component and 10uF capacitor components to bring down cost.
    [BOM.csv, ESP32-S3-WROOM-1U.kicad_sch, JLC_BOM.csv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]
2026-07-16 Updated the input diode to a TVS that is in stock/normally stocked by JLCPCB
    [PowerInput.kicad_sch, USB Input.kicad_sch]
2026-07-21 Updated schematic to use a different TPS54308 buck instead.
    [PowerConversion.kicad_sch]
2026-07-25 Swapped MCP1826 with a TLV767, and updated the layout and silkscreen to match it.
    [MQTT-ModularControllerBoard.kicad_pcb, PowerConversion.kicad_sch]
2026-07-25 Updated layout on pcb slightly.
    [MQTT-ModularControllerBoard.kicad_pcb]
2026-07-26 Updated and tweaked PCB layout.
    [MQTT-ModularControllerBoard.kicad_pcb]
2026-07-26 Updated to remove iva under pad's. Only via's under padas are under the TLV767 now, which should be acceptable as that is for thermal load.
    [MQTT-ModularControllerBoard.kicad_pcb]
2026-07-29 Updated production files. Tweaked traces.
    [BOM.csv, JLC_BOM.csv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]
2026-07-30 Adjusted trace layout to separate GPIO43 and GPIO44 to help prevent crosstalk in case of attempting manual flashing.
    [MQTT-ModularControllerBoard-B_Cu.gbl, MQTT-ModularControllerBoard-B_Mask.gbs, MQTT-ModularControllerBoard-B_Paste.gbp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]
2026-08-02 Silkscreen tweaks for polarity.
    [MQTT-ModularControllerBoard-B_Cu.gbl, MQTT-ModularControllerBoard-B_Mask.gbs, MQTT-ModularControllerBoard-B_Paste.gbp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]
2026-08-04 Update README to reflect testing status
    Added a note indicating the project is currently in testing.
2026-08-08 Updated Jobset to auto generate JLCPCB required files, complete renders, setup schematics etc.
    [JLCPCB_BOM.csv, JLC_BOM.csv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]
2026-08-09 Updated Fab layer and silkscreen.
    [ESP32-S3-WROOM-1U.kicad_sch, MQTT-ModularControllerBoard.kicad_pcb]
2026-08-09 Updated Fab layer and regenerated all outputs.
    [BOM.csv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]
2026-08-16 Silkscreen Updates and BOM added
    [MQTT-ModularControllerBoard.kicad_pcb, PowerConversion.kicad_sch]
2026-09-08 Added ProjectIO Folder for firmware and some initial code.
    [watering_controller.csv]
2026-09-12 Added allowance for selecting specific SSID's and scanning prior to swapping to captive portal.
    [main.cpp]
2026-09-15 Updated to use Serial IsPlugged instead of VBUS Sense due to a mistake on the board.
    [main.cpp, test_configuration.cpp]
2026-09-19 Added module flow template for descriptive coding graph.
2026-09-22 Updates to configuration store and bugfixes. Configuration store now allows only one setting to be applied at a time.
    [FakeNetworkConfigStore.h, main.cpp, test_configuration.cpp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]
2026-09-23 Updates to the status, added configuration serial commands to turn status printing on and off, also added a status command and a command to set the hostname.
2026-09-24 Updated documnetation for sensor module.
2026-09-24 Added solenoid module.
2026-09-25 Cleaned up main to make it more readable and moved the sensor publishing interval to main.
2026-09-25 Initial pump module implementation.
2026-09-29 Updated solenoid MQTT to post the number of solenoids connected on command.
2026-09-30 Fixes for programming mode. Programming flag moved to rtc_noinit to prevent it reloading on a serial monitor restart/close/open. For stability programming mode stays for up to a 1 second disconnect.
    [main.cpp, test_isp.cpp]
2026-10-01 Added a MQTT prefix to be used as an ID on boards.
2026-10-03 First rework attempt, restructured into multiple main modules and submodules.
    [main.cpp, test_configuration.cpp, test_deep_modules.cpp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]
2026-10-03 Updated firmware to first ping modules for any that have already got their addresses set, in case of a reset of the main board not impacting the daughter boards.
    [test_modules.cpp]
2026-10-03 Updates communication to remove errors from NACK's on slots after a reset.
    [test_status.cpp]
2026-10-03 Added sensor count command to the sensor module.
2026-10-10 Added UDPI programmer, and SPI programming on specified slots. No longer accepts generic programming.
    [FakeHalfDuplexUart.h, main.cpp, test_configuration.cpp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]
2026-10-21 Swapped UPDI programming pin to CS pin again.
2026-10-24 Moved UPDI programming to MOD. The Resistor on CS prevents programming.
2026-10-25 Updated firmware to repeatedly send the on command for the pump every 60 seconds unless we run into the 3 minute timeout without the MQTT command.
2026-10-26 Disabled retain on MQTT messages besides the slot status messages
2026-11-09 Updates to headers and docs based on changes to sensor firmware.
2026-11-09 Controller now supports control of the sensors and turning them on off and resetting them.
2026-11-10 Updated firmware to recognise and utilise new firmware / board / commands for the pump module and set an information gathering timeline.
2026-11-10 Updated to prevent publishing of unavailable on pump information topics when the board is unplugged.
2026-11-11 Updated to add a board and firmware version to the main board and publish board and firmware versions for mother and daughter boards.

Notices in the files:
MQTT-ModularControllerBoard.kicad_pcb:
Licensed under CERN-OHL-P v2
